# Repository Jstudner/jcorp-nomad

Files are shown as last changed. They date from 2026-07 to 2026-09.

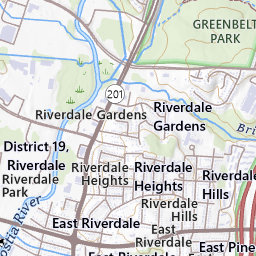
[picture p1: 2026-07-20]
SD_Card_Template/Maps/dc/tiles/14/4691/6263.jpg

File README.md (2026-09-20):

# <div align="center">Jcorp Nomad</div>

<div align="center">
  Jcorp Nomad Offline Media Server
</div>

<p align="center"><b>A portable, offline media server powered by the ESP32-S3 in a thumbdrive form factor.</b><br>
Stream movies, music, books, and shows anywhere - no internet required.</p>

<p align="center">
  
  
  
  
</p>

<p align="center">
  <a href="https://nomad.jcorptech.net"><b>Buy a Prebuilt Nomad</b></a> &nbsp;|&nbsp;
  <a href="https://ko-fi.com/jcorptech"><b>Support on Ko-fi</b></a>
</p>

---

> **Firmware 4.6** - The biggest update since Mk4, and everything in it has come over from the experimental branch. exFAT card support, offline maps with turn by turn directions, game ROMs and a shelf of built-in games, local multiplayer, TV support over DLNA, a WiFi Mode that joins your home network, offline translation, and recipe + 3D model libraries. Everything from Mk4 is still here and still works, this adds on top of it.
>
> Some of this is newer than the rest. The parts I'd call settled are exFAT, the reader and the media pages. Maps, WiFi Mode, DLNA and Translate work are all tested in full, but they have had less time in front of other people's hardware than the rest of the project. Known rough edges are listed near the bottom, everything works but some is getting more improvments so its user friendly. Maps in particular is tricky right now. 
>
> Firmware and the SD card template both change here, so you'll need to reflash and refresh your card files.
>
> Also making a push to migrate fully to exfat, will be keeping fat32 legacy support so yall dont have to reformat your cards, but some of the advanced features will only work on exfat.

---

## What is Nomad

Jcorp Nomad is an open-source offline media server designed for travel, remote work, classrooms, camping, and more. It runs entirely on an ESP32-S3, creates a local Wi-Fi hotspot, and serves media through a browser interface. Multiple users can access separate media streams simultaneously, all without internet access.

This project is compact, easy to modify, and includes optional 3D-printable hardware. Both firmware and web interface are fully open-source.

---

## Get a Nomad

### Build It Yourself (Recommended)

I strongly recommend building your own Nomad. It's not a very difficult project, if you can follow instructions and plug in a USB cable, you can do it. The parts are cheap, widely available, and the whole build takes under an hour. See Hardware Requirements and Quick Start below. If nothing else please check out the DIY option before purchasing. 

### Buy a Prebuilt

That said, I also won't say no to money. If you'd rather skip the DIY and get a ready-to-go unit, prebuilt Nomads are available at **[nomad.jcorptech.net](https://nomad.jcorptech.net)**.

Every Nomad, whether you build it or buy it, runs the same open-source firmware and web interface. When new features and updates are released, you can always flash the latest code yourself to stay up to date. 

### Support Development

If you just want to support the project, donations are always appreciated:  
**[ko-fi.com/jcorptech](https://ko-fi.com/jcorptech)**

---

## What's New in 4.6

### exFAT Support

This is the big one, and it's the thing people have been asking for the longest. FAT32 has been Nomad's biggest limitation since day one, cards over 32GB needed a reformat first, and no single file could go over 4GB, which is why large ZIMs had to be split into parts. exFAT fixes both of those.

- Cards mount as **exFAT, FAT32 or FAT16**, auto detected at boot, nothing for you to configure
- SDXC cards (anything over 32GB) work exactly as they come out of the package, no reformat step at all
- Single files can go over 4GB now, so a full size Wikipedia can sit on the card as one file instead of split parts
- Old FAT32 cards keep working exactly like they always did, this is additive, not a migration
- Writing to a nearly full card is a lot less likely to stall out, that was behind a lot of the upload and save timeouts

The reason this took so long, the Arduino ESP32 core ships a prebuilt filesystem library with exFAT compiled out of it, and there is no way to turn it back on from a sketch. The fix was to stop using it entirely and swap in SdFat, which brings its own filesystem code. Everything else in the firmware talks to it the same way it always did.

**You'll need the SdFat library installed** from the Arduino Library Manager before this will compile.

### Offline Maps

- Map regions live in `/Maps` and get browsed offline, with place search and real turn by turn directions (Drive and Walk)
- Regions are prepped on your PC with Nomad Tools, which downloads the map picture and the road network for the areas you pick
- Reads map data straight out of a packed archive instead of unpacking it onto the card, which keeps a region at roughly its download size instead of several times bigger

This one is the roughest of the bunch. It works, but it's slow, big regions take a while to draw. I'm still working on that, have a few ideas to improve the speed.

### WiFi Mode (join your home network)

Instead of running its own hotspot, Nomad can now join a WiFi network you already have and serve everything to that network, the browser interface, DLNA, all of it. Your phone stays on your normal internet-connected WiFi and Nomad is just another device on it. This is also the fix for TV devices like Fire Sticks that refuse to do anything on a network with no internet.

- Set it up from the admin panel: **WiFi Mode** button in the top bar opens a popup with a network scanner, password field, and an auto-reconnect option
- The captive portal turns itself off in this mode (hijacking DNS on someone's home network is uhh.. lets say frowned upon), and the screen shows the IP address the router assigned instead of a hotspot name

### TV Support (DLNA)

Nomad now shows up as a media server on anything that speaks DLNA - smart TVs, VLC, Kodi, Roku Media Player.

- Browse Movies, Shows, Music and Gallery straight from the TV, with cover art, and seeking works
- On the TV side there's nothing to set up, it just appears in the device list
- Works on the hotspot or in WiFi Mode; for Fire Sticks use WiFi Mode and the VLC app, since Fire OS breaks without internet now (so lame)
- Toggle it off in the admin panel if you don't want Nomad announcing itself / makes everything else a bit faster

### Offline Translation

A Translate page that works with zero internet. Two people can pass a phone back and forth and each type in their own language.

- Language packs live in `/Translate` on the card and are installed with Nomad Tools, which always grabs both directions of a pair
- Translation runs in the browser of whoever connected, nothing heavy runs on the Nomad itself
- will be very slow to load the first time, but after that back and forth is fairly quick, and the info is cached so its quick if you load it again.  
- I will be working on a voice integration on device for this aswell, but most keyboards include it already so voice to voice should be possible too. 

### Cookbook & Workshop

Two new library pages, both optional, both disabled by default.

- **Cookbook:** drop `.md`, `.cook` or `.json` recipe files into `/Cookbook` (photos work, same-name image convention). Recipes render with ingredient and step checklists you can tick off while cooking.
- **Workshop:** drop `.stl`, `.3mf` or `.obj` files into `/Workshop` and preview them in 3D right in the browser. A README or notes file in a folder describes every model in it. The viewer is a few hundred lines of raw WebGL, not a bundled 3D engine, so it stays fast off the card.

- I think these are kinda dumb... but I needed a clean number of pages so this is what we get..
### Game ROMs & Built-in Games

- Drop ROMs into `/Games` and play them in the browser through EmulatorJS
- Ships with Go, Chess, Connect Four, Tic-Tac-Toe, 2048, Minesweeper, Snake, Crazy Eights, Dots and Boxes, and a shared Whiteboard, all just plain HTML files
- Also ships with **DOOM** - the shareware WAD is included, and any `.wad` you drop in `/Games` runs through the same engine (this is here so I can say it runs doom, you must keep this on the card it is load bearing.. I swear lol)
- Cover art works the same as everywhere else, drop an image with the same name next to the file
- Add or remove games by adding or deleting files, there's nothing to configure, this works for the inbuilt games aswell. 

### Local Multiplayer

- Two player game rooms for multidevice use. 
- One person makes a room, shares the 4 character code, the other joins from their own phone
- Chess, Go, Connect Four and Tic-Tac-Toe all support it, the Whiteboard is just a shared freeform board
- There are also "pass and play games" that only need one device, I will eventualy make this an option for all of the defaults. 
- I plan to expand this so most games can run in pass and play or proper multi device mode. 

---

## Mk4 Highlights

### Offline Wikipedia & Archive Support (ZIM)
- Browse and search full offline Wikipedia (and other ZIM archives like Gutenberg and TED) directly from the SD card
- Search is fast even on massive archives, the companion [Nomad Tools](https://github.com/Jstudner/Nomad-Tools) app prebuilds a compact index on your PC, so the device never has to search the raw multi-gigabyte file itself
- Embedded videos and epub books inside archives play/read right in the browser
- Currently tested with Gutenburg epubs, TedX Videos, and wikipedia from the tiny 0.8 file all the way to the 140gb maxi with images. 

### Redesigned Case
<p align="center">
  Nomad Mk4 exploded case view
</p>

- New case slides together **front-to-back** instead of the old top-to-bottom design
- No more direct pressure on the screen, which was a common cause of cracked/broken screens on the old case
- Buttons stay exposed on the outside, so you can still flash firmware or hit the boot button without disassembling anything

### Indexing & Stability
- Root-caused and fixed a long-standing random reboot bug tied to files over 2GB, this was the actual cause of crashes on image-heavy Wikipedia pages and big movie scrubbing
- Fixed a heap-corruption crash that could hit when indexing and refreshing SD totals at the same time
- Boot-time indexing now only re-scans when files have actually changed, instead of a full scan on every boot
- Removed the screens loading spinner that was silently forcing a full-screen redraw every loop, pulling it out made the whole device noticeably more stable

### Reader & Memory Improvements
- Comic and PDF readers now free old pages from memory as you scroll, fixing crashes on long comics and scanned PDFs
- PDF viewer shows a real loading percentage instead of a blank screen
- Cleaned out a bunch of dead code and unused libraries that were loading on every Books page

### UI & Admin Updates
- Unified header and button styling across pages so themes apply consistently everywhere
- Fixed several dark mode readability bugs (unreadable resume text, buttons that ignored custom themes, etc.)
- Admin panel settings are now gated behind a login
- Fixed a stuck brightness slider caused by an out-of-range default value

### Default Themes (28)

Default Blue, Forest Night, Cherry Blossom, Mocha Latte, Ocean Depths,
Autumn Leaves, Lavender Fields, Sunset Horizon, Coral Reef, Mountain Mist,
Jade Garden, Desert Sand, Arctic Aurora, DeLorean, Midnight Code, 90s Retro,
Mint Breeze, Rose Gold, Crimson Night, Emerald Dream, Royal Purple,
Copper Sunset, Sapphire Sea, Peach Cream, Slate Storm, Lime Zest,
Burgundy Wine, Teal Oasis

---

## Features

- **exFAT & FAT32:** Any card format, auto detected at boot. Cards over 32GB and files over 4GB both work.
- **WiFi Mode:** Join an existing WiFi network instead of running the hotspot, with automatic fallback so you can't lock yourself out.
- **TV Support (DLNA):** Shows up as a media server for smart TVs, VLC, Kodi and friends, with cover art and seeking.
- **Offline Encyclopedia:** ZIM archive support for offline Wikipedia and other offline wikis, with fast on-device search.
- **Offline Maps:** Browsable map regions with place search and turn by turn directions, served straight off the card.
- **Offline Translation:** In-browser translation between installed language pairs, no internet ever.
- **Games:** Browser-based ROM playback through EmulatorJS, DOOM, plus ten built-in games.
- **Local Multiplayer:** Two player game rooms over the Nomad's own Wi-Fi, no internet needed.
- **Cookbook:** Recipe library with tick-off ingredient and step checklists.
- **Workshop:** 3D-print model library with an in-browser STL/3MF/OBJ preview.
- **Subtitles:** Sidecar subtitle files attach themselves to a video by filename, with selectable language tracks.
- **Chat:** A simple local chat room for everyone connected to the Nomad.
- **Admin Panel:** Full device controls, library indexing, Theme Customizer, menu page toggles, login-gated settings.
- **File Browser:** Upload, rename, delete, download, and inline file editing. (Recommended to use a PC)
- **Global Search:** Quickly find media across all categories from the Menu page.
- **Music Player:** Seamless background playback with subdirectory playlists and a dynamic Queue.
- **Movies & Shows:** Plyr-integrated playback with season/special folder support.
- **Digital Library:** EPUB support, PDF handling, and a dedicated Comic/Webtoon reader.
- **Resume Tracking:** Saves playback progress for Movies, Shows, and certain Books.
- **Gallery & Files:** Dedicated pages for image viewing, video clips, and general file sharing.
- **Captive Portal:** Automatic login/redirection for easy access.
- **Persistent Settings:** Themes and system configurations saved across reboots.
- **Mobile-Friendly UI:** Fully responsive design optimized for handheld offline streaming.

---

## Hardware Compatibility

Nomad is built specifically for the **Waveshare ESP32-S3 Dev Board (1.47" LCD version)**. Due to the number of low-level tricks used to squeeze this much functionality out of the hardware, it is difficult to get Nomad running on other boards.

There are a few community forks that target other ESP32 boards, but your mileage will vary. I'm also actively working on a **Nomad Lite** version with wider board compatibility, focused on basic streaming without all the advanced features.

---

## Hardware Requirements

- **Waveshare ESP32-S3 Dev Board (1.47" LCD version)** - [Amazon Link](https://amzn.to/4ktB6oT)

- **or the ESP32-S3-LCD-1.47B** - the USB-C board. Same chip, same everything, the LCD backlight just moves from GPIO 48 to GPIO 46. Building it yourself, set `BOARD_USB_C` to 1 in `Display_ST7789.h`; flashing from the browser, pick the USB-C build. Get it wrong and it boots functional, just no screen output. - [Amazon Link](https://link.amazon/B03vYZlXB)

- **microSD card, exFAT or FAT32 (16-128GB recommended, up to 2TB)**
  [Amazon Link](https://amzn.to/44tM1c4)

- **SD-Card Extender (optional, 3DP case compatible)**
  [Amazon Link](https://amzn.to/45IWIJz)

- **USB power source**
- **Optional:** 3D-printed enclosure (STL files included)

---

## Flash It From Your Browser

If you would rather skip Arduino IDE entirely, **[nomadflash.jcorptech.net](https://nomadflash.jcorptech.net)** does the setup from a browser tab. The firmware is already compiled, so there is nothing to install and no SdFat version to line up. This system will lag a bit behind on the latest version, but makes setup much easier for most casual users. 

It covers three things:

- **Flash the firmware.** Plug Nomad into a USB port, pick a build, and it writes the bootloader, partition table and app in one image. Takes less than a minute.
- **Set up the SD card.** Copies the web interface onto the card and creates every media folder Nomad uses, including Games, Maps, Cookbook and Workshop. There is an optional test set of placeholder content if you want to see every page working before you load your own media.
- **Update an existing card.** Replaces only the interface files and leaves your media alone. (still WIP)

Both the main and experimental builds are there, and each is offered for both boards:

- **USB-A** for the ESP32-S3-LCD-1.47
- **USB-C** for the ESP32-S3-LCD-1.47B

Pick the one matching the connector on your board. The two differ only in which pin drives the LCD backlight, so flashing the wrong one boots fine but leaves the screen dark.

Formatting is the one step it cannot do, because a web page has no access to drives or partitions. You usually do not need it, since exFAT, FAT32 and FAT16 cards all mount as they come. If a card does need formatting, the site prints the exact command for Windows, macOS or Linux.

**Requires Chrome, Edge or Opera on a desktop.** It uses Web Serial and the File System Access API, which Firefox and Safari do not implement, and neither one works on iOS or Android.

---

## Software Requirements

- Arduino IDE, with the **esp32 board package 3.3.3**
- Arduino libraries, exact versions. These are what the shipped build compiles against, and mismatches here are the single most common build failure:
  - `ArduinoJson` by Benoit Blanchon **7.3.0**
  - `Async TCP` by ESP32Async **3.4.7**
  - `ESP Async WebServer` by ESP32Async **3.7.1**
  - `LVGL` by kisvegabor **8.4.0**
  - `SdFat` by Bill Greiman **2.3.0** - this one is required for exFAT, it is not optional
- SquareLine Studio (optional, for UI editing)

If you would rather not line any of that up, use the browser flasher above.

---

## Quick Start

1. Flash ESP32-S3 firmware from `/firmware/`.
2. Copy `/SD_Card_Template/` files onto the card. Any exFAT or FAT32 card works as-is, you only need to format if the card is brand new or broken.
3. Place media in `/Movies`, `/Shows`, `/Books`, `/Music`, `/Gallery`, `/Files`, `/Games`, `/Cookbook`, `/Workshop`. (ZIMs, Maps and Translate packs get prepped with Nomad Tools, see below.)
4. Insert SD card and power device via USB.
5. Connect to Wi-Fi `Jcorp_Nomad` with password: `password`.
6. Open the browser interface.
7. Click the gear icon → Library Index → **Full Scan Now**.
8. Monitor Admin Console for progress; scan may take minutes.
9. Return to Menu page and enjoy your media!
10. Optional: to serve your home network (and TVs) instead of running a hotspot, open Admin → **WiFi Mode** and join your network from there.

---

## Key Improvements

1. **Faster & More Reliable Indexing**
   - Non-blocking, background indexing for large libraries.
   - Safe on power loss; partial indexes remain intact.
   - Auto-updates changes; frontend detects updates automatically.
   - Boot-time indexing now only triggers on an actual file change, not every boot.

2. **Resume Functionality**
   - Movies and Shows track playback progress.
   - Options for **Play from Start** or **Resume**.
   - Menu displays last three movies/shows; mobile shows most recent.

3. **Dark Mode**
   - Toggleable across all pages from the menu.
   - Consistent theme tokens across pages, no more mismatched dark colors.

4. **Admin Page**
   - Full device control: shutdown, restart, flash mode, Wi-Fi, RGB LEDs, brightness, credentials, indexing, and file management.
   - Login-gated settings so changes require the admin password.
   - Safe shutdown option for SD card health.
   - Real-time system console feedback.

5. **Stability Improvements**
   - Fixed frontend NDJSON sync issues.
   - Crash recovery on large indexes.
   - Fixed a random-reboot bug tied to files over 2GB.
   - Dynamic LCD brightness adjustment.
   - Streaming stability enhancements.

6. **Improved Library Support**
   - Supports deeper folder structures for Shows and Music.
   - Flexible organization; media files can be nested at any level.

---

```
Folder Structure

/Movies
    Interstellar.mp4
    Interstellar.jpg

/Shows
    /The Office
        S01E01 - Pilot.mp4
        S01E02 - Diversity Day.mp4
    The Office.jpg

    /Gravity Falls
        /Season 1
            S1E1 - Tourist Trapped.mp4
            S1E2 - The Legend of the Gobblewonker.mp4
        /Season 2
            S2E1 - Scary-oke.mp4
            S2E2 - Into the Bunker.mp4
        Alex Hirsch Interview.mp4
    Gravity Falls.jpg

/Books
    The Martian.pdf
    The Martian.jpg
    /How to Train Your Dragon
        book1.pdf
        book2.mp3
        book1.jpg
        book2.jpg
    How to Train Your Dragon.jpg

/Music
    track01.mp3
    /Artist1
        track01.mp3
        /Album1
            track02.mp3
    /PersonName
        /Playlist1
            track01.mp3
        /Playlist2
            track02.mp3

/Gallery
    image01.jpg
    video01.mp4

/Files
    document.pdf
    example.txt

/Games
    Pokemon Red.gb
    Pokemon Red.png
    Doom.wad
    Chess.html
    Go.html

/Cookbook
    Grandma's Chili.md
    Grandma's Chili.jpg
    /Desserts
        Brownies.md

/Workshop
    /Brackets
        shelf bracket.stl
        README.txt

/Maps
    /pennsylvania
        manifest.json
        (map data, prepped with Nomad Tools)

/Translate
    manifest.json
    (language packs, installed with Nomad Tools)

/Archive
    wikipedia_en_all_maxi.zim
    /.nomad-zim
        (search index, built by Nomad Tools)

index.html
appleindex.html
menu.html
movies.html
shows.html
books.html
music.html
gallery.html
files.html
archive.html
games.html
maps.html
translate.html
cookbook.html
workshop.html
Logo.png
favicon.ico
```

---

## Supported Formats

- **Video:** `.mp4, .webm, .m4v` play everywhere. `.mkv, .avi, .mov` are listed and handed to the player too, but Nomad has no content type for them, so whether they play is down to your browser (Safari is usually fine with `.mov`, Chrome usually is not with `.mkv`). If a video lists but will not play, that is almost always this. Remux to `.mp4` and it will.
- **Audio:** `.mp3, .flac, .wav, .ogg, .aac, .m4a`, plus `.opus` with the same browser caveat as above.
- **Subtitles:** `.srt, .vtt, .ass, .ssa, .sub` - drop them next to the video with the same name. `Movie.srt` or `Movie.en.srt` both attach, language suffixes become selectable tracks, and `.srt` is converted to WebVTT on the fly because browsers render nothing for raw SRT.
- **Books:** `.pdf, .epub, .cbz, .cbr` 
- **Images:** `.jpg, .jpeg, .png, .webp, .gif, .bmp, .avif` 
- **Archives:** `.zim` (offline Wikipedia and other ZIM-format wikis), needs special processing, you cant just drop a .zim in sadly. Prep them with [Nomad Tools](https://github.com/Jstudner/Nomad-Tools) first (still rough, but handles most common ZIMs)
- **Games:** ROMs for the systems EmulatorJS supports (GB, GBC, GBA, NES, SNES, Genesis, and others), `.wad` files for DOOM, plus `.html` files for built-in games
- **Maps:** map regions prepped with Nomad Tools, dropped into `/Maps`
- **Recipes:** `.md`, `.cook`, or `.json` files in `/Cookbook`
- **3D Models:** `.stl`, `.3mf`, `.obj` in `/Workshop`
- **Translation:** language packs installed into `/Translate` with Nomad Tools

---

## Nomad Tools

Some content needs a one-time prep step on your computer before Nomad can use it, ZIM archives need a search index built, maps need downloading, translation packs need fetching. [Nomad Tools](https://github.com/Jstudner/Nomad-Tools) is a simple menu that does all of it. Windows and Linux (macOS untested).

Basic usage:

1. Download Nomad Tools and put your Nomad card in the computer.
2. **Windows:** double-click `START-Windows.bat`. **Linux:** run `./start-linux.sh`.
3. Pick your card from the list (or type its path), then pick a job from the menu.

What the menu covers:

- **Add ZIM archives** - copies Wikipedia/Gutenberg/etc. onto the card and builds the search index. Adds to what's there, never wipes your existing archives, and splits oversized files automatically.
- **Optimize cover images** - shrinks Movie/Show/Book covers so pages load fast on the device.
- **Rebuild media index** - refreshes the library listing after you've added or removed files from the PC.
- **Download offline maps** - grabs map tiles for an area you pick, with a size estimate and free-space check before anything downloads.
- **Build a routing map** - maps plus the road network and place search, for turn by turn directions. Pick from ready-made areas (any US state, big regions, or the whole country) and they join into one seamless map. US only for now
- **Add translation languages** - installs offline translation packs, always both directions of a pair. Comes in collections (`starter`, `traveler`, `europe`, `asia`, `world`) or single languages. (I recomend just grabbing all as its less than 4GB)

A good order for a fresh card: media and ZIMs first, optimize images, rebuild the index last. Maps and languages can be added any time.

---

## Known Rough Edges

Everything here works, but these are the parts I already know aren't great:

- **Maps are slow.** Big regions take a while to load and pan. It works, it's just not snappy yet, and that's the main thing I'm working on.
- **WiFi Mode and DLNA have seen few routers and few TVs.** They work (tested with VLC on a Fire Stick, desktop VLC, and phones), but there are a lot of both out there and I have tried a handful. If your TV can't find Nomad, tell me what TV it is and I will see what I can do.
- **Some video containers list but won't play.** `.mkv`, `.avi` and `.mov` get served without a content type, so it comes down to what your browser will sniff and decode. Nothing is broken on the Nomad side.
- **Set an admin password before using WiFi Mode.** On the hotspot only people you gave the password to can reach the admin panel. On your home network, everything on that network can. I dont hard gate this, but worth noting. 
- **Free space on FAT32 cards can read slightly wrong.** SdFat doesn't update the counter FAT32 keeps for it, so the number drifts by however much Nomad itself writes. It fixes itself the next time you plug the card into a PC, and it doesn't affect your files at all. exFAT cards aren't affected.
- **EmulatorJS cores download on first play.** Once cached they're fine, but the first launch of a system pulls the core off the card and takes a moment.
- The newer features have had a fraction of the testing the core has. If something breaks, tell me. Issues and PRs are both welcome.

---

## What's Next

**Nomad Lite** - A stripped-down version of Nomad with wider board compatibility, focused on core streaming features. In active development now that Mk4 is out.

**Gallion** - A larger-scale sibling to Nomad, built on more capable hardware. Gallion is designed to handle everything that couldn't fit on Nomad's current platform > ROM emulation, 4k video, and expanded media compatibility across the board. The current version is [here](https://github.com/Jstudner/Gallion).

**ESP32-P4** - I have said for a long time that I don't want to switch hardware, as doing so would leave yall with a useless board. The S3 is the Nomad and it stays supported. That said, I have started slowly co-developing a P4 version alongside it, because the P4 brings two things the S3 can't: a radio module that is already FCC certified, which matters a lot for anything I sell, and considerably faster WiFi. 

Two boards, if it works out. The **WIFI6** board is a stick, only a bit larger than the Nomad you have now. The **NANO** is noticeably bigger than either, but it adds an ethernet port with POE module support, and a USB port so storage can be expanded or replaced rather than living entirely on the SD card.

None of this is a replacement announcement. It will be its own branch, the S3 keeps getting the same updates, just better speed and a few more features on the p4 branch. 

---

## Project Inspiration

Inspired by my experience running a Jellyfin server, I wanted a portable, low-cost solution for offline media streaming. Challenges with SBCs (Raspberry Pi, etc.) included high power usage, heat, and instability.

Nomad focuses on delivering:

- Offline access
- Wide device compatibility
- Simple frontend for media browsing and playback
- Multiple user support
- High customization potential

The ESP32-S3 provides enough performance to handle these requirements efficiently, in a pocket-sized form factor.

---

## License

[CC BY-NC-SA 4.0](https://creativecommons.org/licenses/by-nc-sa/4.0/) - free to remix and share for non-commercial use with attribution.

---

## Credits

Developed by **Jackson Studner (Jcorp Tech)**.
Inspired by open-source offline media projects. Contributions via PRs welcome.

<p align="center">
  
</p>

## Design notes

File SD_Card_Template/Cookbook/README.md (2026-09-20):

# Cookbook

Recipes for the Nomad's Cookbook page. Drop files in here, then turn the page on
in **Admin → Menu Pages → Cookbook** (it ships off).

Subfolders become categories — `Cookbook/Bread/Cornbread.md` shows up under
"Bread". One level deep; anything deeper isn't scanned.

## Writing recipes on the Nomad itself

You don't have to prepare files on a computer. The Cookbook page has a
**＋ New recipe** button that writes straight to this folder, and an **Edit**
button on every recipe. What it saves is ordinary Markdown in the format below,
so a recipe typed on a phone is still a plain file you can open on a PC later.

Editing and deleting follow the admin's **Allow uploads** switch — turn that off
and the Cookbook becomes read-only, without hiding the recipes.

## Timers

Any time written into a step becomes a tappable timer: "bake 20-25 minutes"
gets a **⏲ 20 min** button beside it (ranges start at the low end, so you come
back and check). There's also a manual timer at the bottom of the dock.

Timers keep running while you move around the page, survive a reload, hold the
screen awake, and beep when they finish. They're per-browser, not stored on the
card, so two people cooking from the same Nomad don't fight over them.

## Three formats

Any of them works, and they can be mixed in the same folder.

### Markdown (`.md`) — easiest to type by hand

```markdown
---
title: Skillet Cornbread
servings: 8
time: 35 min
category: Bread
tags: cast iron, quick
source: Grandma
---

A crisp-edged cornbread that comes out of a hot skillet.

## Ingredients
- 1 cup cornmeal
- 1 cup flour
- 1 1/2 tsp salt
- 2 eggs

## Steps
1. Heat the oven to 425°F with the skillet inside.
2. Whisk the dry ingredients together.
3. Bake 20-25 minutes until the top springs back.

## Notes
Buttermilk instead of milk makes it tangier.
```

The `---` block at the top is optional; so is every field in it. A `# Heading`
before the first section works as the title if there's no front matter.

### JSON (`.json`) — easiest to generate

```json
{
  "title": "Skillet Cornbread",
  "servings": 8,
  "time": "35 min",
  "category": "Bread",
  "tags": ["cast iron", "quick"],
  "ingredients": ["1 cup cornmeal", "1 1/2 tsp salt", "2 eggs"],
  "steps": ["Heat the oven to 425°F.", "Bake 20-25 minutes."],
  "notes": "Buttermilk instead of milk makes it tangier."
}
```

Ingredients may also be objects — `{"qty": 1, "unit": "cup", "item": "cornmeal"}` —
which come out as the same scalable line.

### Cooklang (`.cook`) — recipe-as-a-sentence

[Cooklang](https://cooklang.org) tags ingredients, cookware and timers inline in
the method, and the ingredients list builds itself:

```cooklang
>> title: Cooklang Pancakes
>> servings: 4
>> time: 20 minutes
>> course: Breakfast

Whisk the @flour{200%g}, @milk{300%ml} and @eggs{2} in a #mixing bowl{}.

Cook a ladle of batter in a #frying pan{} for ~{2%minutes} until it bubbles,
then flip. Serve with @maple syrup{}.
```

`@ingredient{qty%unit}` (use `{}` when the name is more than one word),
`#cookware{}` and `~timer{5%min}` are lifted out automatically; `>> key: value`
lines are metadata (`servings` still drives scaling). See
`Example - Cooklang Pancakes.cook`.

## Photos

An image with the same name as the recipe becomes its photo:
`Skillet Cornbread.md` + `Skillet Cornbread.jpg`. Or set `image:` in the recipe
to any path on the card.

## Serving scaling

The page reads the leading amount off each ingredient line and multiplies it
when you change the serving count. It understands `2`, `1.5`, `1/2`, `1 1/2`,
`½`, `1½`, and ranges like `2-3` or `2 to 3`.

Lines that don't start with a number — "salt to taste", "a handful of parsley" —
are left exactly as written, because they don't scale. Unit names aren't
converted either: 8 tsp stays 8 tsp rather than becoming 2 tbsp 2 tsp.

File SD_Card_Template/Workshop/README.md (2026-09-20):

# Workshop

3D models for the Nomad's Workshop page. Drop files in here; the Workshop tile
appears on the menu as soon as this folder has anything in it.

Subfolders become collections — `Workshop/Repairs/Hose Clip.stl` shows up under
"Repairs". One level deep; anything deeper isn't scanned.

## What can be previewed

| Format | On the page |
|---|---|
| `.stl` (binary or ASCII) | Full 3D preview, dimensions, triangle count |
| `.obj` | Full 3D preview |
| `.3mf` | Full 3D preview, including multi-part plates |
| `.gcode`, `.step`, `.f3d`, `.scad`, `.zip`, and friends | Listed and downloadable, no preview |

The preview is drawn with plain WebGL off the card — nothing is fetched from the
internet, and no slicer is involved.

## Thumbnails and descriptions

Files that sit next to a model and share its name are picked up automatically:

```
Hose Clip.stl          the model
Hose Clip.jpg          its photo
Hose Clip.md           its description / print notes
README.md              a description shared by everything in this folder
```

A few common suffixes are understood too, so all of these attach to
`Hose Clip.stl` rather than being ignored:

```
Hose Clip-notes.md
Hose Clip.description.txt
Hose Clip print settings.txt
```

An exact name match always wins over a suffixed one. Images may be `.jpg`,
`.png`, `.webp`, `.gif` or `.bmp`; descriptions may be `.md`, `.txt` or `.nfo`,
and are shown as plain text, so write them however you like. A folder-wide
description can be called `README`, `notes` or `description`.

Where the photo shows up:

- in the grid, as the model's thumbnail
- for `.stl` / `.obj` / `.3mf`, behind a **Photo** button next to the 3D view,
  so you can compare the model with how it actually printed
- for everything else — `.gcode`, `.step` and friends — the photo *is* the
  preview, filling the space where the 3D view would be

## Print check

The model view compares the model's real bounding box against a build volume you
set once (stored in your browser, not on the card). It counts a part as fitting
if it fits either way round on the plate, since rotating 90° costs nothing.

Dimensions come from the model's own geometry, so this only applies to the
formats that get parsed — a `.gcode` or `.step` is reported as unknown rather
than guessed at.

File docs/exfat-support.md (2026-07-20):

# exFAT + FAT32 SD card support

Nomad firmware 4.6 replaces the Arduino `SD_MMC` filesystem stack with
**NomadSD** (`firmware/JcorpNomadProject/NomadSD.h/.cpp`), which mounts
**exFAT, FAT32 and FAT16** cards interchangeably, auto-detected at boot.

Cards larger than 32 GB work exactly as they come out of the box, since SDXC
cards ship exFAT. Existing FAT32 cards keep working unchanged: format support
is additive, not a migration.

## Why SD_MMC could never do exFAT

The Arduino-ESP32 core links a **precompiled** ESP-IDF FATFS library built with
`FF_FS_EXFAT = 0`. No sketch-level setting can re-enable it, so `SD_MMC`,
`FFat` and anything else on `esp_vfs_fat` is FAT32-only, permanently. Years of
attempts through that stack went nowhere because the limit lives in a `.a` file.

## How NomadSD works

```
sdmmc_host driver (same SDMMC peripheral + pins as before)
  -> SdMmcBlockDev        raw-sector block device (FsBlockDeviceInterface)
    -> SdFat FsVolume     auto-detects exFAT / FAT32 / FAT16 at mount
      -> fs::FSImpl wrap  standard Arduino fs::FS + fs::File
        -> NomadSD        drop-in for SD_MMC (`#define SD_MMC NomadSD`)
```

SdFat carries its own MIT-licensed FAT/exFAT implementation, so the locked IDF
FATFS is no longer used. The web server, indexer and every existing `SD_MMC.*`
call site work unchanged through `fs::FS`.

## Build requirements

- **SdFat library** >= 2.3.0 (Library Manager: "SdFat" by Bill Greiman).
- `build_opt.h` in the sketch folder, already in the repo. The ESP32 core picks
  it up automatically in both the IDE and arduino-cli. It sets
  `USE_BLOCK_DEVICE_INTERFACE=1`, UTF-8 long filenames, and incremental
  free-space accounting.
- Board settings and partition scheme are unchanged.

## What this buys

### Files larger than 4 GB stream

`fs::File` is 32-bit end to end: `size()`, `position()` and `seek()` all use
`size_t`, so a 5 GB file reported 0.88 GB and could not be seeked past 4 GB.
That API is fixed by the core.

`NomadFile64` (in `NomadSD.h`) is a 64-bit read handle used by the HTTP range
handler instead. Sizes come from `NomadSD.fileSize64()`, offsets parse with
`strtoull`, and the stream table stores `uint64_t`. Two related fixes:

- A range starting beyond EOF returns **416** with a `Content-Range`, per
  RFC 9110, instead of being silently clamped.
- Any single response body is capped at 256 MB so it fits `size_t`. A plain GET
  of a larger file degrades to **206** with an honest `Content-Range` rather
  than a truncated 200; clients fetch the next slice, which media players and
  the ZIM reader already do.

### `size()` saturates instead of wrapping

`NomadFileImpl::size()` returns `SIZE_MAX` past 4 GB rather than wrapping to a
small number. `SIZE_MAX` doubles as a sentinel: the indexer, file browser and
usage scanner check for it and only then pay for a `fileSize64()` lookup.
Normal files, and every file on a FAT32 card, cost nothing extra.

### The 2 GB stdio guard is gone

Mainline had to close and reopen a streaming handle crossing 2 GB, because
`fs::File` sat on newlib stdio whose signed 32-bit offset corrupted the FILE
buffer on a reused handle. SdFat does not use stdio and seeks 64-bit natively,
so deep seeks no longer pay a close/reopen, on exFAT and FAT32 alike.

### Fewer stalls on full cards

Creating a file no longer scans a huge FAT for free clusters, which was the
main aggravator behind `/save` and `/upload` watchdog resets on nearly-full
cards. Contiguous-file seeks are O(1) instead of a cluster-chain walk.

### File timestamps

An `FsDateTime` callback is installed at mount. Without one every file the
device writes gets an identical constant date. The device is offline with no
RTC, so this uses the fixed-epoch-plus-uptime approach already used for OPDS
timestamps: not wall time, but files written later in a session sort after
earlier ones.

## Behaviour notes

- The boot log and admin console report the detected filesystem and bus mode,
  e.g. `Mounted 4-bit @ 40MHz (exFAT)`.
- Mount tries 4-bit/40 MHz, then 4-bit/20 MHz, then 1-bit/20 MHz. The last rung
  matches the old behaviour, so any board or card that cannot do 4-bit still
  comes up.
- **USB mode no longer mounts a filesystem.** MSC passes raw sectors and the
  host PC handles the format. The old `format_if_mount_failed=true` in USB mode,
  which could silently reformat an exFAT card as FAT32, is gone.
- FAT32 free space is read from the FSInfo sector; exFAT uses the allocation
  bitmap. A card with broken FSInfo falls back to a one-time full FAT walk.
- All SD I/O is serialized by one recursive mutex inside NomadSD, replacing the
  FATFS `FF_FS_REENTRANT` volume lock.

## Verification

`arduino-cli` build: 50% flash, 42% RAM, 720 bytes below mainline.

Filesystem behaviour is covered by a host harness linking the same SdFat version
the firmware uses, through the same block-device interface, against real disk
images. All 30 checks pass:

- **FAT32**: mounts through the same part1-then-superfloppy order, finds root
  and nested files written by an external tool, reads correct content, reports
  exact sizes, seeks, iterates directories, and round-trips a new file.
- **exFAT**: mounts, reports correct volume geometry, creates a 5 GiB file,
  reports the full 64-bit size, seeks past 4 GiB, writes and reads back a marker
  there, and survives a reused handle crossing the 2 GiB and 4 GiB lines, the
  exact pattern that used to corrupt newlib stdio.

`fsck.exfat` reports the SdFat-written volume clean.

## Known issue: FAT32 free-space counter drifts

`fsck.vfat` on a FAT32 image after SdFat wrote to it reports:

```
Free cluster summary wrong (129815 vs. really 129814)
```

SdFat does not update the FAT32 **FSInfo** sector when it allocates clusters.
The old FATFS did, so this is a small regression on FAT32 cards only.

- **Scope**: drifts by exactly the clusters the device itself writes (index
  files, config, uploads). File data is unaffected and nothing risks corruption.
- **Visibility**: FSInfo is advisory. Windows and Linux recompute free space
  rather than trusting it; only `chkdsk`/`fsck` remarks on it, and any PC write
  resets it. The dirty bit is not set, so there is no "repair this drive" prompt.
- **Effect on us**: `usedBytes()` seeds from FSInfo for a fast boot and inherits
  the drift. The firmware will not trust that fast path until
  `reconcileStatTrust()` agrees with a real walk to within 2%.
- **Not applicable to exFAT**, which has no FSInfo.

Fixes if it ever matters: write a corrected FSInfo at unmount, or mark FSInfo
unknown (`0xFFFFFFFF`, explicitly legal) on first write and accept one full FAT
walk on the next boot. Neither is implemented; the current behaviour is bounded
and self-correcting.

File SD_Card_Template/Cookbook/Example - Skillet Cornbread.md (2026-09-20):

---
title: Skillet Cornbread
servings: 8
time: 35 min
category: Bread
tags: cast iron, quick, side
---

Crisp-edged cornbread baked in a skillet that goes into the oven empty and hot.
Delete this file once you've added recipes of your own — it's here to show the
format.

## Ingredients
- 1 cup cornmeal
- 1 cup flour
- 2 tbsp sugar
- 1 1/2 tsp salt
- 2 tsp baking powder
- 1 1/4 cups buttermilk
- 2 eggs
- 6 tbsp butter
- salt to taste

## Steps
1. Put the skillet in the oven and heat both to 425°F.
2. Whisk the cornmeal, flour, sugar, salt and baking powder together.
3. Beat the buttermilk and eggs, then stir them into the dry mix until just combined — a few lumps are fine.
4. Melt the butter in the hot skillet, swirl to coat, and pour the rest into the batter.
5. Pour the batter into the skillet. It should hiss.
6. Bake 20-25 minutes, until the top springs back and the edges have pulled away.
7. Turn it out onto a board and cut it in the skillet's shape.

## Notes
Try the serving buttons above the ingredients — the amounts rescale as you go.
"salt to taste" stays put, because that one doesn't scale.

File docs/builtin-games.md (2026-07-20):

# Built-in games system (Games bucket)

## How it works

Any `.html` file inside `/Games` on the SD card is treated as a **built-in game**
and shows up on the Games page (`games.html`) as a card in the same grid as ROMs:

- Built-ins are **pinned above the ROM list** and are not re-ordered by the sort
  dropdown. Pin order is the `BUILTIN_ORDER` list in `games.html`
  (`go`, `connect four`, `chess`, `tic-tac-toe`, `whiteboard`); anything not in
  the list follows alphabetically.
- The card label is the filename without `.html` (`Connect Four.html` becomes "Connect Four").
- **Cover art** uses the same sidecar convention as ROMs: put an image with the
  same basename next to the file (`Go.png` beside `Go.html`) and it becomes the
  card cover. Until then the shared `placeholder.jpg` is used.
- **Add / remove**: drop an `.html` in `/Games` to add it; delete the file to
  remove it from the frontend. Nothing else to configure. (The Games index
  rebuilds on demand: after changing files via USB, the next visit may briefly
  show "Building game index".)
- The console filter dropdown hides built-ins (they have no console); the search
  box still matches their names.

Shipped built-ins live in `SD_Card_Template/Games/`:

| File | Needs | Notes |
|---|---|---|
| `Go.html` | `/assets/tenuki.min.js` (MIT, engine-only esbuild bundle of tenuki 0.3.1) | 9×9 / 13×13. 19x19 is not offered because the move list would outgrow the 512-byte MP state. |
| `Connect Four.html` | none | |
| `Chess.html` | `/assets/chess.min.js` (chess.js **0.12.1**, BSD-2) | 0.13+ is ESM-only and breaks as a classic `<script>`, so do not "upgrade" it. |
| `Tic-Tac-Toe.html` | none | |
| `Whiteboard.html` | none | Not a room game, see below. |

All two-player games share `/assets/mp-client.js` (HTTP short-polling against the
firmware's `/api/mp/*` room store: 4-char room codes, seat 0 = creator, turn =
`seq` parity, state = one opaque string ≤ ~500 bytes replaced on every move).

### Go state encoding

`{"s":13,"m":"ddqf..pp"}` where `m` is the move list, two chars per move
(`'a'+x`,`'a'+y`), `..` = pass. Every client rebuilds the position by replaying
the list into a fresh tenuki game, which also hands mid-game joiners the whole
board on their first poll. Scoring note: territory score is shown after two
passes **without dead-stone marking**, so casual-play accuracy only.

## Whiteboard

Same control set as the old Gallion whiteboard (Private/Live modes, undo/redo,
color, pen size, erase, clear, save, load) but the live board syncs through the
SD card instead of sockets (the firmware has none):

- Every participant writes **their own stroke layer** to
  `/.whiteboard/wb_<clientid>.json` via the open `POST /save` handler (atomic
  temp+rename on the firmware side), throttled to ≥0.9 s between writes and
  capped at 24 KB per layer.
- Everyone polls `GET /listfiles?dir=/.whiteboard` every 2.5 s and refetches only
  layers whose file size changed. Per-client layers mean no lost strokes from
  concurrent drawing.
- **Clear** on the live board `POST /delete`s every layer file. Other clients
  detect the wipe because their own file disappears from the listing, and reset.
- The private board autosaves strokes to `localStorage`; **Save** downloads a
  PNG, **Load** (private only) draws an image file onto the canvas.
- The `/.whiteboard` dotfolder is invisible to the media indexers (dot-prefixed)
  and is created on first save via `POST /mkdir`.

## EmulatorJS (ROM cards)

- Runtime lives at `/EmulatorJS/data/` (loader.js, emulator.min.js/.css,
  version.json, `compression/`, `localization/`, `cores/`).
- Cores staged on the card (4 build variants each): gambatte (GB/GBC),
  fceumm (NES), snes9x (SNES), genesis_plus_gx (Genesis/Master System),
  mgba (GBA) ≈ 24 MB. More cores: copy `<core>/*.data` from the EmulatorJS
  repo's per-core directories into `data/cores/`.
- `data/cores/reports/<core>.json` must exist per core or EmulatorJS disables
  **core caching** (the ~1 MB core re-downloads on every play, costly over the
  ESP32 link). The report content is trivial build metadata
  (`{"core":...,"buildStart":...,"buildEnd":...,"options":{}}`); synthesized
  ones are fine. The core itself downloads only after the user taps Start Game.
- `games.html` maps UI console ids to EmulatorJS system keys before launch
  (`gbc` to `gb`, `genesis` to `segaMD`, `sms` to `segaMS`), since EmulatorJS has **no** `gbc`
  system key; an unmapped id makes the loader fetch a nonexistent core and die.
- An "Exit Game" bar appears above the emulator; exiting reloads the page
  (EmulatorJS cannot be torn down and restarted in one page lifetime).
- Save states/saves persist in the browser (IndexedDB), keyed by ROM path
  (`EJS_gameID`).

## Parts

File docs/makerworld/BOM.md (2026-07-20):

# Jcorp Nomad Mk4 — Bill of Materials

Total cost: roughly **$20–30** depending on SD card size.

## Electronics

| # | Part | Qty | Notes | Link |
|---|---|---|---|---|
| 1 | Waveshare ESP32-S3 Dev Board, **1.47" LCD version** | 1 | The only supported board — Wi-Fi, display, SD slot, and USB-A plug all on one PCB. No substitutes without firmware work. | [Amazon](https://amzn.to/4ktB6oT) |
| 2 | microSD card, 16–128 GB (up to 2 TB supported) | 1 | **Class 10 / U1 or better** — Nomad is very read-heavy and a fast card noticeably improves performance. Must be formatted FAT32. | [Amazon](https://amzn.to/44tM1c4) |
| 3 | USB power source | 1 | Any USB-A port, charger, or power bank. | — |

## Optional

| # | Part | Qty | Notes | Link |
|---|---|---|---|---|
| 4 | microSD extender (case-compatible length) | 1 | Swap the card from the back of the case without disassembly; also moves the card away from board heat. | [Amazon](https://amzn.to/45IWIJz) |
| 5 | Small thermal pad or dab of thermal paste | 1 | Between the ESP32-S3 chip and case shell. Not required — air cooling works fine. | — |

## Printed parts

| # | Part | Qty | Material | Notes |
|---|---|---|---|---|
| 6 | Nomad Mk4 case body | 1 | **PETG** (recommended) or quality PLA | ~10–15 g total. No supports. |
| 7 | Nomad Mk4 front cover (screen side) | 1 | PETG or PLA | Slides on front-to-back; snap fit (can be glued). |

## Software (all free)

| Tool | Purpose |
|---|---|
| [Arduino IDE](https://www.arduino.cc/en/software) | Flash the firmware |
| [FAT32Format GUI](https://fat32format-gui.en.lo4d.com/windows) | Format >32 GB cards as FAT32 on Windows |
| [HandBrake](https://handbrake.fr) | Compress video (Fast 480p preset recommended) |
| [Nomad Tools](https://github.com/Jstudner/Nomad-Tools) | Optional — prep offline Wikipedia/ZIM archives |
| [SquareLine Studio](https://squareline.io) | Optional/advanced — edit the device's on-screen UI |

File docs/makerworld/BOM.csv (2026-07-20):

Item | Part | Qty | Required | Notes | Link
1 | Waveshare ESP32-S3 Dev Board, 1.47" LCD version | 1 | Yes | Only supported board; Wi-Fi + display + SD slot + USB-A on one PCB | https://amzn.to/4ktB6oT
2 | microSD card 16-128 GB (up to 2 TB supported), Class 10/U1+ | 1 | Yes | FAT32 format required; fast card = better performance | https://amzn.to/44tM1c4
3 | USB power source (port, charger, or power bank) | 1 | Yes
4 | microSD extender (case-compatible length) | 1 | No | Card access from back of case without disassembly; reduces heat exposure | https://amzn.to/45IWIJz
5 | Thermal pad or paste (small) | 1 | No | Between ESP32-S3 chip and shell; air cooling works fine without
6 | Printed: Nomad Mk4 case body | 1 | Yes | PETG recommended (heat), no supports
7 | Printed: Nomad Mk4 front cover | 1 | Yes | Slides on front-to-back, snap fit

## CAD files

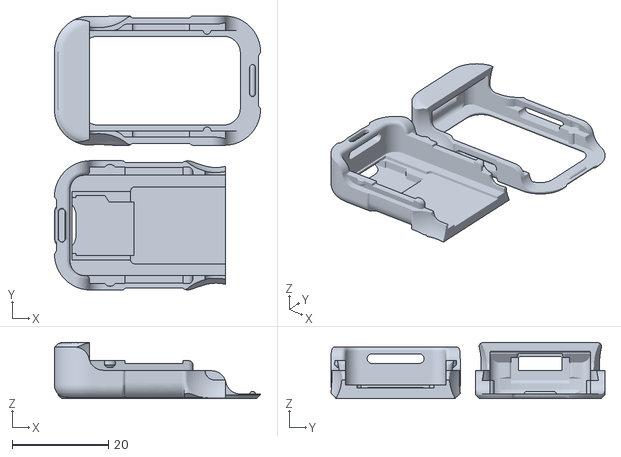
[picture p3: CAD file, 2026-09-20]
NomadCasev30_USB-C.stl
42.8 x 56.8 x 11.7

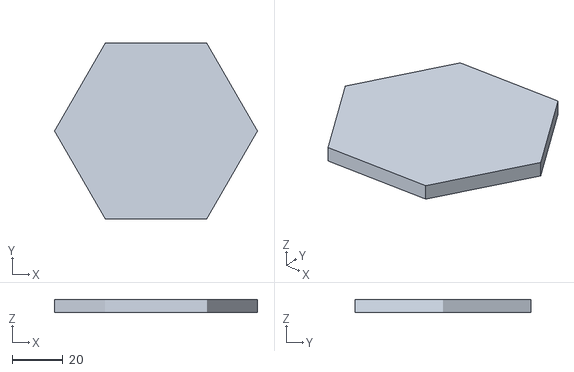
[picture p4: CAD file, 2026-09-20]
SD_Card_Template/Workshop/Hex Coaster 80mm.stl
80.0 x 69.3 x 5.00

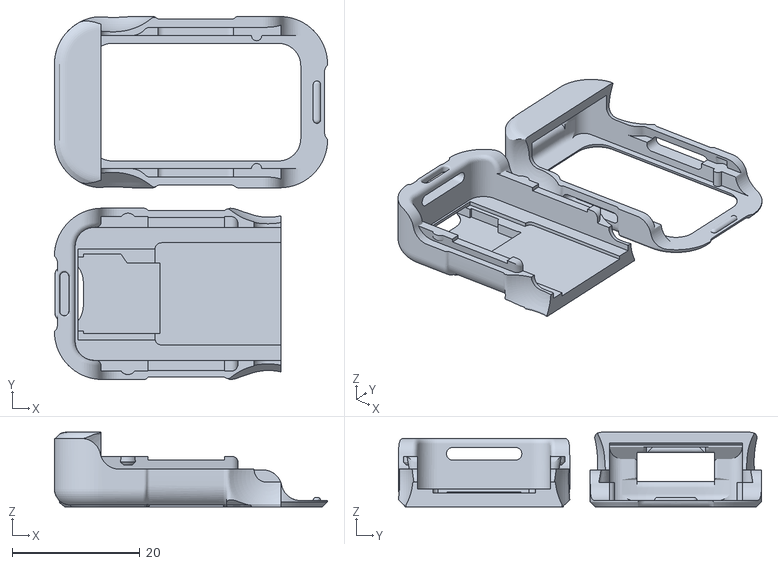
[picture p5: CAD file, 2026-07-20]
NomadCasev30.stl
42.8 x 56.8 x 11.7

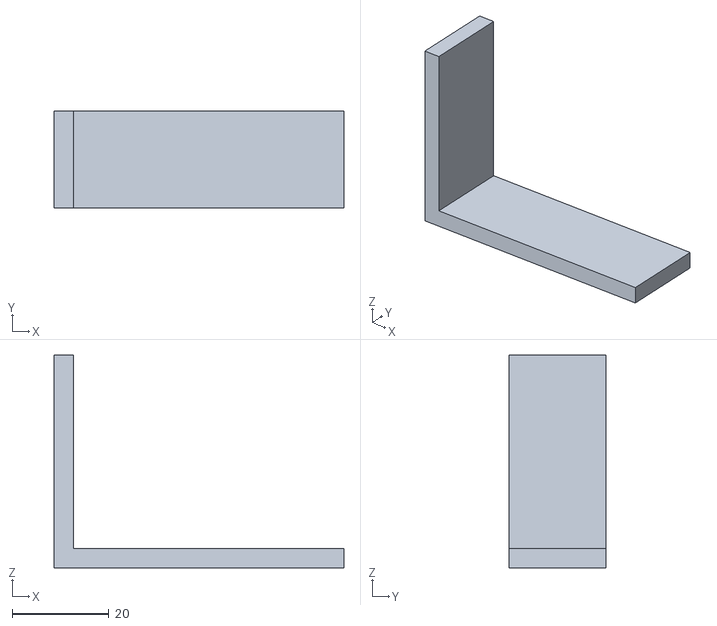
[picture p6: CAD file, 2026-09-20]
SD_Card_Template/Workshop/L Bracket 60mm.stl
60.0 x 20.0 x 44.0

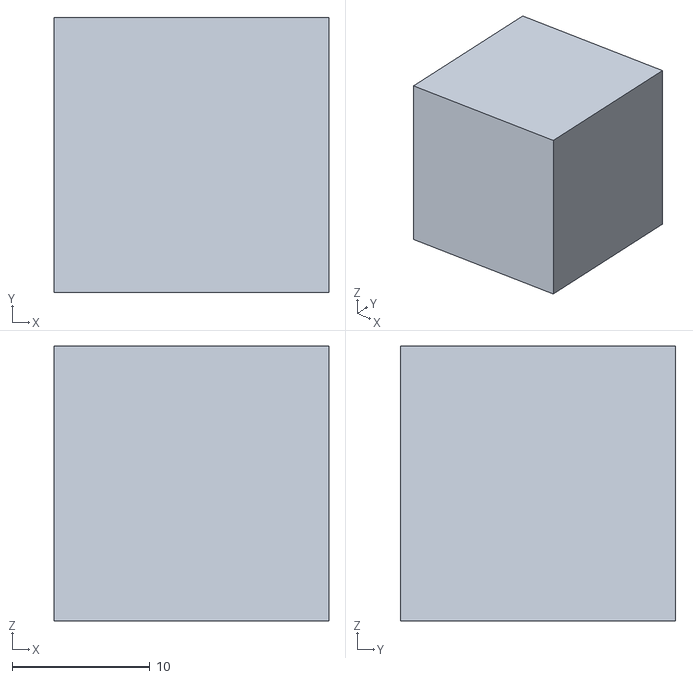
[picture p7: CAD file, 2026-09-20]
SD_Card_Template/Workshop/Calibration Cube 20mm.stl
20.0 x 20.0 x 20.0

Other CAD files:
SD_Card_Template/Archive/.nomad-zim/words-0.skp
SD_Card_Template/Archive/.nomad-zim/words-1.skp
SD_Card_Template/Archive/.nomad-zim/words-2.skp
SD_Card_Template/Archive/.nomad-zim/words-3.skp
SD_Card_Template/Archive/.nomad-zim/words-4.skp
SD_Card_Template/Archive/.nomad-zim/words-5.skp
SD_Card_Template/Archive/.nomad-zim/words-6.skp
SD_Card_Template/Archive/.nomad-zim/words-8.skp
SD_Card_Template/Archive/.nomad-zim/words-a.skp
SD_Card_Template/Archive/.nomad-zim/words-b.skp
SD_Card_Template/Archive/.nomad-zim/words-c.skp
SD_Card_Template/Archive/.nomad-zim/words-d.skp
SD_Card_Template/Archive/.nomad-zim/words-e.skp
SD_Card_Template/Archive/.nomad-zim/words-f.skp
SD_Card_Template/Archive/.nomad-zim/words-g.skp
SD_Card_Template/Archive/.nomad-zim/words-h.skp
SD_Card_Template/Archive/.nomad-zim/words-i.skp
SD_Card_Template/Archive/.nomad-zim/words-j.skp
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

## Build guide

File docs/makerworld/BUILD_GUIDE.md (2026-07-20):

# Jcorp Nomad — Simple Build Guide

Total time: about an hour (plus print time). No soldering, no wiring.

**Golden rule: test everything BEFORE snapping the case together.** The snap tabs weaken a little each time you open it, and the screen is fragile.

---

## Step 1 — Print the case

- **Material:** PETG recommended (the board runs warm); quality PLA is fine too
- **Supports:** none · **Layer height:** 0.2 mm · **Infill:** 15%+
- If your printer's tolerances run tight, print at **101% scale** and size down if loose
- Parts: case body + front screen cover (slides on front-to-back)

## Step 2 — Flash the firmware

1. Download/clone the repo: https://github.com/Jstudner/jcorp-nomad — you need **everything** in `firmware/JcorpNomadProject/`
2. Install [Arduino IDE](https://www.arduino.cc/en/software)
3. **File → Preferences → Additional Board Manager URLs**, add:
   `https://raw.githubusercontent.com/espressif/arduino-esp32/gh-pages/package_esp32_index.json`
4. **Tools → Board → Board Manager** → install **"esp32 by Espressif Systems"**
5. Plug the board into a USB port (it plugs in like a flash drive) and set under **Tools**:

   | Setting | Value |
   |---|---|
   | Board | ESP32S3 Dev Module |
   | Port | your COM port |
   | USB CDC On Boot | Enabled |
   | Flash Size | 16MB (128Mb) |
   | Partition Scheme | 16MB Flash (3MB APP/9.9MB FATFS) |
   | PSRAM | OPI PSRAM |
   | Upload Speed | 921600 |
   | USB Mode | USB-OTG (TinyUSB) |

6. **Tools → Manage Libraries**, install these **exact versions**:
   - ArduinoJson (Benoit Blanchon) **v7.3.0**
   - Async TCP (ESP32Async) **v3.4.7**
   - ESP Async WebServer (ESP32Async) **v3.7.1**
   - LVGL (kisvegabor) **v8.3.10**
   - SdFat (Bill Greiman) **v2.3.0**
7. Open `JcorpNomadProject.ino` and click **Upload**. Done when you see "Done uploading."

> **Stuck in a bad state / board not detected?** Enter flash mode manually: hold **BOOT**, press and release **RESET**, then release **BOOT**.
> **"No such file or directory" library errors?** Wrong library version — clean your Arduino libraries folder and reinstall just the ones above.

## Step 3 — Prepare the SD card

1. Format the card as **FAT32** (Windows won't do >32 GB cards natively — use the free [FAT32Format GUI tool](https://fat32format-gui.en.lo4d.com/windows), allocation size 32K, quick format ✅)
2. Copy everything from the repo's `SD_Card_Template/` folder to the card root
3. Add your media:

```
/Movies   Interstellar.mp4 + Interstellar.jpg   (poster = same name, .jpg)
/Shows    /The Office/S01E01 - Pilot.mp4 ... + The Office.jpg
/Music    mp3/flac/wav — artist/album/playlist folders all work
/Books    PDF, EPUB, CBZ/CBR comics, MP3 audiobooks + matching .jpg covers
/Gallery  photos and video clips
/Files    anything you want to share
```

**Media tips:**
- FAT32 limit: no single file over **4 GB**
- Compress video with [HandBrake](https://handbrake.fr): **Fast 480p preset, H.264, RF 22–24, "Web Optimized" checked, burn in subtitles** — smaller files = more simultaneous streams
- Name episodes `S01E01 - Title.mp4` — everything sorts alphabetically
- Get poster art from [themoviedb.org](https://www.themoviedb.org)
- Offline Wikipedia/ZIM archives need prep with [Nomad Tools](https://github.com/Jstudner/Nomad-Tools) first — you can't just drop a .zim on the card

## Step 4 — First boot & test

1. Insert the SD card, plug into USB power
2. Connect a phone/laptop to Wi-Fi **`Jcorp_Nomad`**, password **`password`**
3. The media menu should open automatically (captive portal); if not, browse to `http://nomad.local/` or `192.168.4.1`
4. Open the **gear icon → Library Index → Full Scan Now** and let it index (a few minutes for big libraries)
5. Play a video. If it streams, you're golden.

## Step 5 — Assemble the case

- Start from the **USB side**, press down gently, and slide the cover front-to-back — the far end from the USB goes on last
- **Be gentle around the screen** — the case exists to protect it, don't let it do the breaking
- Buttons stay exposed, so you never need to open it again for firmware updates

### Heat notes
The board runs warm under load — that's normal, air cooling is fine (all testing was done air-cooled). Optional: a small thermal pad between the ESP32-S3 chip and the shell, and the SD extender keeps the card away from the heat.

---

**Problems?** Check the [GitHub discussions](https://github.com/Jstudner/jcorp-nomad/discussions) — most issues are already documented — or drop a comment.

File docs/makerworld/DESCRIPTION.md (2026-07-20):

# Jcorp Nomad — Pocket Offline Media Server (ESP32-S3)

**A portable, offline media server in a thumbdrive form factor.** Nomad creates its own Wi-Fi hotspot and streams movies, shows, music, books, comics — even full offline Wikipedia — to any phone, tablet, or laptop nearby. No internet, no app, no accounts. Just connect and play.

This is the 3D-printed case + full build for the open-source **Jcorp Nomad Mk4** project. If you can plug in a USB cable and follow instructions, you can build one — the whole build takes under an hour and the parts cost about $20–30.

![Cover image — NomadCoverMK4v2.png]

---

## What it does

- Creates a local Wi-Fi hotspot (captive portal — devices auto-open the media menu)
- Streams to **multiple users at once**, each watching their own thing
- **Movies & Shows** with resume playback, poster art, and season folders
- **Music** with playlists, shuffle, and a live queue
- **Books**: PDF, EPUB, comics (CBZ/CBR), and MP3 audiobooks
- **Offline Wikipedia** and other ZIM archives, with fast search (Mk4)
- Photo gallery, general file sharing, and a full admin panel
- 28 built-in themes + dark mode
- Runs entirely off a microSD card — no soldering, no wiring, no assembly beyond the case

## The case (Mk4)

Slides together **front-to-back** so there's never pressure on the fragile screen (the #1 cause of broken displays on the old design). The buttons stay exposed, so you can flash firmware or reboot without opening it up.

This case is a remix of [ESP32 C6 with LCD Screen Enclosure Case](https://makerworld.com/en/models/2121443-esp32-c6-with-lcd-screen-enclosure-case) by [Adrian](https://makerworld.com/en/@user_1765744671) — full credit for the original design.

## What you need (full BOM in the files)

| Part | Notes |
|---|---|
| Waveshare ESP32-S3 Dev Board, **1.47" LCD version** | The only board Nomad targets — it's the whole computer |
| microSD card, 16–128 GB, Class 10/U1+ | FAT32. Bigger works (up to 2 TB) |
| USB power source | Any USB-A port or charger |
| SD card extender *(optional)* | Lets you swap the card without opening the case |
| ~10–15 g of filament | PETG recommended — the board runs warm |

## Print settings

- **Material:** PETG strongly recommended (device gets warm under load); quality PLA works
- **Layer height:** 0.2 mm · **Walls:** 2+ · **Infill:** 15%+
- **Supports:** none needed
- Snap-fit tolerances: if your printer runs tight, scale to **101%** and adjust down from there

## Setting it up (full guide in the files)

1. Print the case
2. Flash the firmware with Arduino IDE (settings + library versions in the build guide)
3. Format the SD card FAT32, copy the SD template from GitHub, add your media
4. Assemble the case — **after** testing everything works
5. Connect to Wi-Fi `Jcorp_Nomad` (password: `password`) and enjoy

## Links

- **Source code, firmware, and SD template:** https://github.com/Jstudner/jcorp-nomad
- **Step-by-step Instructable:** https://www.instructables.com/Jcorp-Nomad-Mini-WIFI-Media-Server/
- **Prebuilt units** (if DIY isn't your thing): https://nomad.jcorptech.net
- **Support the project:** https://ko-fi.com/jcorptech

Fully open source under **CC BY-NC-SA 4.0**. Firmware and web UI are actively developed — flash the latest code any time to get new features. Featured on [Hackaday](https://hackaday.com/2025/07/13/jcorp-nomad-esp32-s3-offline-media-server-in-a-thumbdrive/).

*Built something with it? I'd love to see it — drop a comment or a build photo.*

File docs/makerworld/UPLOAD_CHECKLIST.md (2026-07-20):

# MakerWorld Upload Checklist

## Post it as a REMIX
The Mk4 case is derived from [ESP32 C6 with LCD Screen Enclosure Case](https://makerworld.com/en/models/2121443-esp32-c6-with-lcd-screen-enclosure-case) by Adrian. When uploading, use MakerWorld's **"Remix" flow from that model page** (or link it as the remix source in the upload form) — that handles attribution properly and keeps you compliant with the original's license. Check the original model's license tag before picking yours; a remix must carry a compatible license.

- Suggested license: **CC BY-NC-SA 4.0** (matches the Nomad repo), if the original allows it.

## Files to upload
- [ ] Case 3MF / print profile — from repo `docs/`: `NomadFullTest.3mf` (plate) — verify it's the current Mk4 parts before upload
- [ ] `AssembledFullTest.3mf` / `AssembledFullTestsingle.3mf` — assembled-view variants, decide which is the print plate vs. display model
- [ ] Consider exporting clean per-part STLs with real names (e.g. `NomadMk4_Body.stl`, `NomadMk4_Cover.stl`) — MakerWorld shows filenames to users
- [ ] `BOM.csv` / `BOM.md` (attach as project files)
- [ ] `BUILD_GUIDE.md` content → paste into the MakerWorld "Assembly/Guide" or description section

## Images (MakerWorld wants several; real photos rank better than renders)
- [ ] Cover: `NomadCoverMK4v2.png` (repo root)
- [ ] Exploded view: `NomadMk4Explode.png`
- [ ] Screen close-up: `NomadNewScreen.png`
- [ ] Real photo of the assembled unit in hand / plugged into a power bank
- [ ] Screenshot of the web UI on a phone (menu + a movie playing)
- [ ] Photo of the printed parts on the plate

## Description
- Paste `DESCRIPTION.md` → fix the image placeholder, verify all links.
- ⚠️ **Affiliate links:** the BOM uses your Amazon affiliate links (`amzn.to/...`). MakerWorld has restrictions on external/affiliate links in descriptions — check current policy; safest is plain product names in the description and affiliate links only on GitHub/Instructables.
- Category suggestion: Electronics → Gadgets. Tags: `esp32`, `esp32-s3`, `media-server`, `offline`, `wifi`, `travel`, `camping`, `open-source`.

## Print profile settings (for the profile upload)
- PETG, 0.2 mm layer, 2+ walls, 15% infill, no supports
- Note in profile description: scale 101% if snap fit is too tight

## Cross-link when live
- [ ] Add the MakerWorld model link to the GitHub README ("Mk4 case files" section currently just says "in this repo")
- [ ] Add it to the Instructable's Case step
- [ ] `[ADD MAKERWORLD LINK]` placeholders anywhere you keep project links (jcorptech.net, Ko-fi page)

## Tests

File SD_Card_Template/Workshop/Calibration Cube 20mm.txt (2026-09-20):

The classic first print. 20 x 20 x 20 mm.

Print at 0.2mm layers, no supports. Measure the sides with calipers
afterwards: all three should read 20.0mm. If X or Y is off, check belt
tension; if Z is off, check your first layer squish.

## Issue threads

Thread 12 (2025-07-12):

ESPAsyncWebServer.h: No such file or directory

brock, 2025-07-12:
Building in Arduino IDE is throwing this error:

```
~/jcorp-nomad/firmware/JcorpNomadProject/JcorpNomadProject.ino:4:10: fatal error: ESPAsyncWebServer.h: No such file or directory
    4 | #include "ESPAsyncWebServer.h"
      |          ^~~~~~~~~~~~~~~~~~~~~
compilation terminated.
exit status 1

Compilation error: ESPAsyncWebServer.h: No such file or directory
```

Jstudner, 2025-07-12:
Howdy! This is an easy fix! go [here](https://github.com/Jstudner/jcorp-nomad/releases/tag/library) and download /unzip the library folder. Point Arduino at those, or clean out your library files and place these there. (on windows its usually C:\Users\<User>\Documents\Arduino\libraries

also if you don't have a libraries file yet just drop the extracted folder in Arduino and it should fix your issue!

Vandypointe2, 2025-08-16:
> Howdy! This is an easy fix! go [here](https://github.com/Jstudner/jcorp-nomad/releases/tag/library) and download /unzip the library folder. Point Arduino at those, or clean out your library files and place these there. (on windows its usually C:\Users<User>\Documents\Arduino\libraries
>
> also if you don't have a libraries file yet just drop the extracted folder in Arduino and it should fix your issue!

So I tried to do this, but when I drop the extracted folder in, it continually just restarts and show the projects files as jumbled. I am not really sure how to fix the libraries as I have tried to import as a zip, and it tells me that it is not a library zip correctly formatted, and I have not been able to manually place it in the sketch folder location as a libraries folder. Do you have a tutorial video I could follow in some way for the firmware flashing portion of all of this?

Jstudner, 2025-08-16:
Howdy! If you use the latest version of the code from GitHub I actually fixed the library issue all together. When did you download the actual code from GitHub? Let me know and I will help you troubleshoot!

Jstudner, 2025-08-16:
Actually I know exactly what the issue is, I just tested it my bad 😅. Still super simple you need to manually grab a few library's. Go to the library manager and you can add them there. I'll update the docs tonight with the exact versions.

Vandypointe2, 2025-08-16:
Honestly I know nothing about any of this, so its all new, but looking at the project files its apparent that its way over my head. Fingers crossed I can get it working.

Jstudner, 2025-08-16:
I should be able to get you through it without too much more trouble. Trying to make it as beginner friendly as possible so the feedback certainly helps. (Also YouTube video tutorial coming soon editing is hard 😅)

Here is what you need to get it running. On the left side panel of Arduino IDE there are 5 icons, the middle one looks like books and when clicked says "library manager"

You need to search for and install the following library's and then it should compile fine

"ArduinoJson" by Benoit Blanchon v7.3.0
"Async TCP" by ESP32Async v3.4.7
"ESP Async Webserver" by ESP32Async v 3.7.1
"LVGL" by kisvegabor V8.4.0

Pay attention to the versions, some will work but best to keep the same ones. Install each and then try compiling again, should fix your problem!

Vandypointe2, 2025-08-17:
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

I was able to get it all flashed and running. Changed the SSID and other settings. I  put an MP4 into the SD storage in the movie folder and it shows in the admin files view, just like the sample videos, but in the movies area of the main menu, there are no types of media in any of the selections, even though I know the board can see it all. Even after gen of the json. I am not sure where I am wrong here.

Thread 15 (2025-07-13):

Impossible to compile

alfem, 2025-07-13:
Hi!

This looks like an amazing project! I used a portable media streamer years ago, in long trips with my little sons. But this DIY solution is really interesting (and portable).

However, I can not compile it. I tried both, main an experimental branches. I moved my usual libraries away and put your zipped libraries in place.

But compile process gives these errors:
```

/prog/jcorp-nomad/firmware/JcorpNomadProject/Display_ST7789.cpp: In function 'void Backlight_Init()':
Display_ST7789.cpp:217:3: error: 'ledcAttach' was not declared in this scope
   ledcAttach(EXAMPLE_PIN_NUM_BK_LIGHT, Frequency, Resolution);
   ^~~~~~~~~~
/prog/jcorp-nomad/firmware/JcorpNomadProject/Display_ST7789.cpp:217:3: note: suggested alternative: 'ledcAttachPin'
   ledcAttach(EXAMPLE_PIN_NUM_BK_LIGHT, Frequency, Resolution);
   ^~~~~~~~~~
   ledcAttachPin

/prog/jcorp-nomad/firmware/JcorpNomadProject/Wireless.cpp: In function 'int ble_scan_number()':
Wireless.cpp:44:51: error: cannot convert 'BLEScanResults' to 'BLEScanResults*' in initialization
   BLEScanResults *foundDevices = pBLEScan->start(5);
                                                   ^
```

The only libraries I have not replaced are the esp32/hardware ones.

Any clue?

Jstudner, 2025-07-14:
Howdy! Glad you are excited about the project! Let me see if I can help. I would start by checking you are using the same Arduino version, it shouldn't matter but I wouldn't be that surprised, I use 2.3.4. Next thing is for the board manager are you using esp32 ver 3.1.3. I havent personaly hit the same error as you before, but it seems like the newer versions use different calls, which is why you get that error. (also double check you setup the tools section correctly for the waveshare board.) let me know if that does the trick, if not ill look into it some more!

Jstudner, 2025-07-14:
any chance you are using a Tdongle board instead of the waveshare one? I just got a similar error trying to work with that board.

Jstudner, 2025-07-15:
Howdy! Check relieses on the main page, as it says in the instructibles the libraries are really specific so best to just download and use the zip included.
https://github.com/Jstudner/jcorp-nomad/releases/tag/library

This has the exact ones to use.

Best of luck! I'll look into the lv_conf next!

weecc-git, 2025-07-15:
Thank you so much. I just copied the lv_config_template from the lvl library and renamed it lv_conf.h and dropped it into the same level as lvl, and that allowed the compile to continue. Thanks again for you work on this project!

Jstudner, 2025-07-15:
Good catch, I will update both of those! I am about to update with a new editable UI for the LCD, so had to change a bunch anyway. Thanks for letting me know!

weecc-git, 2025-07-15:
Final note: I managed to successfully compile and upload the firmware ONLY after setting the Arduino IDE parameter Flash Size to 16MB from the default 4MB. Otherwise the firmware will upload but the device will be locked in a boot loop because the partition topology is incorrect.

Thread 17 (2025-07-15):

[Feature Request] ZIM / Kiwix support

gjgradem, 2025-07-15:
This is an amazing project and i'm soon to build my own! What would make this even more amazing is perhaps adding support for Kiwix / zim files so it not only is an entertainment device, but also a survival device!

Cheers and good luck with this amazing project!

Jstudner, 2025-07-15:
Ill take a crack at this, Really good idea actually!

Jstudner, 2025-07-15:
Ok, yea after looking into it a bit it should be doable, but there are a few things: Fat32 limits the max individual file size to 4gb > zim files can be downloaded in a split format under 4gb each, that being said the support for file splitting looks less than ideal. Any Zim you can download under 4gb will work by default, but you may need to mess around with online tools to split larger ones, and getting full Wikipedia may not be great. Ill be working it it though!

Also going to add a script to the sd card files for running the webserver off a PC so the data isn't stuck on the device if it gets damaged!

Jstudner, 2025-07-15:
I will put a reader for it together, its handled fully in the browser so it might run a bit slow but it will defiantly work to some extent. If I can find a reliable way to split zims I will make a guide! For now I am going to focus on basic functionality, but I think I can just yoink their frontend that already supports slits.

Jstudner, 2025-07-15:
But yes, esp32 only supports fat32, which is nice in some ways, but yea it mostly sucks lol, the bigger brother to this thing is going to run with an ARM based chip, so that will fix like... literally everything

gjgradem, 2025-07-15:
Haha you have a lot of knowledge about these ESP's. Limitations exist and that's fine. Then i think the comment you made about creating basic functionality will be more then fine. I just ordered the ESP and am very curious to see if i can install it! Amazing work man. Thanks :)

Jstudner, 2025-07-18:
That could work, but the issue is that many of my libraries don't work in exfat, its much less common for esp32. not impossible but a lot of work for a minor feature, would possibly need to scratch build some.

As far as file splitting goes it seem like support for that has widely ended. I have seen a few tools, but many complaints about it corrupting files and not being reliable. I am still planning to get some level of ZIM support since it makes sense to have though, and there are way to split files so if I can get it reliable I will post documentation of that too!

Jstudner, 2025-07-29:
ok, I have been doing a bunch of work getting polish done on Nomad so I can update main. after revisiting this for a few hours I have decided I am not going to support kiwix just yet. I can get it to work as long as the files are under 4gb, but I cant get a reliable method for splitting larger files that doesn't break them. I will add support to the bigger version of nomad I am setting up next though! I love the idea, but it shines with a large library and I just cant get that yet.

Closed 2025-07-29.

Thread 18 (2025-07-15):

No display / No WiFi

tylerobara, 2025-07-15:
I have flashed from this repo on my macbook and windows. No errors. I have tried it in a few different USB power bricks and computers and I can never get a wifi network to show up or anything on the display. Any troubleshooting steps or tips for this situation?

Jstudner, 2025-07-15:
Howdy! You can also use Arduino ide (magnifying glass in top right) for serial, sometimes a bit more reliable. that being said could you send a bit more of the serial output? part 3 usually means that the partition scheme is messed up, but it sounds like you already addressed that, you might try enabling "erase all flash before sketch upload" Its a bit above the partition scheme option in tools, that could be the issue. keep me posted, and if you can send me a chunk of the serial output!

Jstudner, 2025-07-15:
this error is showing your chip as only having 4mb of memory not 16: ` exceeds flash chip size 0x400000`
What board are you working with? Might be a weird read error, you might try reseting it by clicking and holding the left button, then clicking the right button and releasing, then releasing the left button (all while powered on).

Jstudner, 2025-07-15:
you might even try setting flash to 4MB (1MB APP / 1.9MB FATFS) and try, wont run well but if it compiles we will know some more

Jstudner, 2025-07-15:
I read that wrong, the one in IDE is going to be 4mb with fatfs (1.2MB APP / 1.5MB FATFS) >>>> not (1 /1.9)

tylerobara, 2025-07-15:
> this error is showing your chip as only having 4mb of memory not 16: ` exceeds flash chip size 0x400000` What board are you working with? Might be a weird read error, you might try reseting it by clicking and holding the left button, then clicking the right button and releasing, then releasing the left button (all while powered on).

Here is the item I got from Amazon: https://www.amazon.com/dp/B0DFTCC1FT?ref=ppx_yo2ov_dt_b_fed_asin_title
"Built-in 512KB SRAM and 384KB ROM, with onboard 16MB Flash and 8MB PSRAM. Onboard 1.47inch LCD display, 172×320 resolution, 262K color"

Jstudner, 2025-07-15:
Try erasing the flash again, it sounds like it got partitioned weird

tylerobara, 2025-07-15:
Maybe it was this, it was set to 4MB 🤦

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

tylerobara, 2025-07-16:
Getting closer, seems like it's starting and crashing:
```
=== ESP32-S3 Captive Portal & SDMMC Server ===
ESP-ROM:esp32s3-20210327
Build:Mar 27 2021
rst:0x3 (RTC_SW_SYS_RST),boot:0x8 (SPI_FAST_FLASH_BOOT)
Saved PC:0x40376be6
SPIWP:0xee
mode:DIO, clock div:1
load:0x3fce2820,len:0x1150
load:0x403c8700,len:0x4
load:0x403c8704,len:0xc24
load:0x403cb700,len:0x30b4
entry 0x403c88b8

=== ESP32-S3 Captive Portal & SDMMC Server ===
ESP-ROM:esp32s3-20210327
Build:Mar 27 2021
rst:0x3 (RTC_SW_SYS_RST),boot:0x8 (SPI_FAST_FLASH_BOOT)
Saved PC:0x40376be6
SPIWP:0xee
mode:DIO, clock div:1
load:0x3fce2820,len:0x1150
load:0x403c8700,len:0x4
load:0x403c8704,len:0xc24
load:0x403cb700,len:0x30b4
entry 0x403c88b8

=== ESP32-S3 Captive Portal & SDMMC Server ===

=== ESP32-S3 Captive Portal & SDMMC Server ===

=== ESP32-S3 Captive Portal & SDMMC Server ===

=== ESP32-S3 Captive Portal & SDMMC Server ===
```
The very first time I was able to scan and find the wifi network but it doesnt seem to stay booted anymore. I'm gonna try another flash.

Jstudner, 2025-07-16:
Yea it's crashing, but still loading it as 4mb so that's the main reason. I think you need to check all of your settings one by one. You need to enable the settings for cleaning / removing flash on load. When I get home in an hourish if you are still stuck I'll send a pic of what it should look like. Also make sure you have the board type set to esp32s3 dev board.

tylerobara, 2025-07-16:
I had arduino side by side with your settings this last time. Ill research some kind of manual partition wipe then re-flash

Jstudner, 2025-07-16:
Best of luck, again keep me posted! Always happy to help!

Jstudner, 2025-07-16:
well, sorry it isn't working for you but I will be around tomorrow to help, I can also call if you need!

Jstudner, 2025-07-19:
Here is the setup, be sure to set it as esp32s3 dev module in settings as well. If you have trouble with library not found errors check the GitHub versions, there is a zip of all my libraries you can replace yours with (you basically must do this). Let me know if it works, happy to help troubleshoot!

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

chrisallick, 2025-07-19:
Ok, I was able to get the basic microsd example working, loading images and what not on the screen. So I know its working. Huh... I am not sure what is going on. I will try your libraries and start over.

Jstudner, 2025-07-20:
Yea 90% of the issues so far have been due to the libraries, download and unzip the "libraries" folder, and then delete your old libraries folder and put this one in its place (or if you do Arduino stuff often just replace everything inside. It's usually in /username/documents/Arduino/libraries on windows

chrisallick, 2025-07-20:
oof i tried your libraries folder and it immediately started puking up errors. i couldn't get it to compile.

Jstudner, 2025-07-20:
Show me what error you got, I can walk you though it. Also happy to do a discord call or something if you need more help!

chrisallick, 2025-07-20:
Ignore, im a moron. I was deleting my libraries folder and just dumping into Arduino folder :) It works haha.

I'd love to figure out how to get it working with updated libraries and not just black box replacing everything, but it is working. It's not playing back my mp4s. And I'll be excited to see it support mkv.

Jstudner, 2025-07-20:
New file support is coming very soon! glad you could get it working! enjoy!

Closed 2025-07-20.

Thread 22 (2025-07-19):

Waveshare ESP32-S3 USB-C Black Screen Issue

daninykh, 2025-07-19:
I was having an issue with the screen being dark, even though I was uploading Waveshare's stock firmware just fine.

I'm not sure if it's because I'm using the USB-C version, but I had to change the pin num for backlight in, "Display_ST7789.h".

It's at the top of the file, originally it was set to 48 but following the waveshare demo has it set to 46.

```
#pragma once
#include <Arduino.h>
#include <SPI.h>
#define LCD_WIDTH   172 //LCD width
#define LCD_HEIGHT  320 //LCD height

#define SPIFreq                        80000000
#define EXAMPLE_PIN_NUM_MISO           -1
#define EXAMPLE_PIN_NUM_MOSI           45
#define EXAMPLE_PIN_NUM_SCLK           40
#define EXAMPLE_PIN_NUM_LCD_CS         42
#define EXAMPLE_PIN_NUM_LCD_DC         41
#define EXAMPLE_PIN_NUM_LCD_RST        39
#define EXAMPLE_PIN_NUM_BK_LIGHT       46   <----- Change this from 48 to 46
#define Frequency       1000         
#define Resolution      10
```

I am using only files as the instructable guide with libraries copied from the instructables as well.

Hope this helps someone!

Jstudner, 2025-07-19:
That is super helpful! Could I get the amazon link or the exact product number? Glad you managed to get it working though! and thank you for the update!

daninykh, 2025-07-19:
https://a.co/d/2PQ3kJo

I choose the USB-C version purely because I thought it looked sleeker lol.

And, no, thank you! I named my SSID "DoomsDay"

Closed 2025-07-19.

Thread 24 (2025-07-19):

Flashed deviced. RGB pixel noise when SD Card inserted.

chrisallick, 2025-07-19:
Ok, I got it compiling and running, but when I put the sd card in hte screen is just random pixels. its just rgb white noise.

serial monitor is spitting this out repeatedly? Any thoughts? without SD card i can see the wifi network.

```
assert failed: tcp_alloc /IDF/components/lwip/lwip/src/core/tcp.c:1854 (Required to lock TCPIP core functionality!)

Backtrace: 0x4037671d:0x3fcbac70 0x4037e77d:0x3fcbac90 0x4038544a:0x3fcbacb0 0x420573a7:0x3fcbadf0 0x4205750d:0x3fcbae10 0x42010bdd:0x3fcbae30 0x4200edfe:0x3fcbae80 0x420056ca:0x3fcbaea0 0x4203b3fb:0x3fcbaf00 0x4037f452:0x3fcbaf20

ELF file SHA256: d9dc8883c

Rebooting...
ESP-ROM:esp32s3-20210327
Build:Mar 27 2021
rst:0xc (RTC_SW_CPU_RST),boot:0x8 (SPI_FAST_FLASH_BOOT)
Saved PC:0x4037b68e
SPIWP:0xee
mode:DIO, clock div:1
load:0x3fce2820,len:0x1150
load:0x403c8700,len:0x4
load:0x403c8704,len:0xc24
load:0x403cb700,len:0x30b4
entry 0x403c88b8

```

chrisallick, 2025-07-19:
Might have found the issue with ESPAsyncWebServer version

chrisallick, 2025-07-19:
https://imgur.com/a/8fAUa8Q

chrisallick, 2025-07-19:
Shoot I thought I had figured it out. I switched board configs to ESP32S3 Dev Module. I was using Waveshare ESP32 S3 1.47LCD (which seemed right) https://www.waveshare.com/wiki/ESP32-S3-LCD-1.47#Resources

Still not working with SD Card inserted.

New configuration: https://imgur.com/a/xf3HsLz

I've also noticed the SSID does not read JCORP_NOMAD

Jstudner, 2025-07-20:
Is the SD card in when you power it? that can cause the first issue. the white noise is usually boot, you can disable that in firmware to an extent. that being said it sounds like an issue with the web system. did you change the default ssid and password? If the password is less than 8 characters you will get pretty much the same issues so that might be it. let me know, I am happy to help get it up and running!

chrisallick, 2025-07-20:
Copying over the entire libraries folder worked. I was disappointed I couldn't get it working with standard library installs, but I think the code base is relying on nuanced branches and patches.

chrisallick, 2025-07-20:
Oh I did change the password and it was only 5 characters! Wow, ok well it is working with your suggested method of copying over libraries folder. Now Im going to start over and try and get it working from scratch with updated libs. This is so cool. I'm so excited.

Jstudner, 2025-07-20:
glad that worked haha, Ima be so real it took a miracle to get the original libraries working, and at this point I think ima just add to the docs requiring people to do it, basically every library takes an exact version.

Enjoy!

Jstudner, 2025-07-20:
> Oh I did change the password and it was only 5 characters! Wow, ok well it is working with your suggested method of copying over libraries folder. Now Im going to start over and try and get it working from scratch with updated libs. This is so cool. I'm so excited.

Its a dumb requirement of the captive portal (for your phone to let it redirect), haven't found a way around it yet sorry!

chrisallick, 2025-07-20:
Im taking your libraries folder, compiling, testing, and deleting down one by one till I get to a diff. At a minimum that will help.

chrisallick, 2025-07-20:
oh im almost positive that is what it is :) hahah

Jstudner, 2025-07-20:
Ain't that just the way it goes 😅

chrisallick, 2025-07-20:
Ok, i moved RGB_Lamp files to the project folder and out of libs. They aren't trackable via the arduino ide.

Libraries required (nothing else in my libraries folder):

Very good:

ArduinoJson 7.4.2 - standard library installed via Arduino IDE - works fine. Deleted your version and overrode it with the library manager version. works ok for me.

Async TCP 3.4.5 - standard library installed via Arduino IDE - works fine.  Deleted your version and overrode it with the library manager version. works ok for me.

ESP Async WebServer 3.7.10 - standard library installed via Arduino IDE - works fine.  Deleted your version and overrode it with the library manager version. works ok for me.

Not as great, but not bad at all:

lvgl 8.3.10 (your version) -> 9.3.0 (latest) - installed via Arduino IDE, copied over the template config file... failed. you're on 8.3.10... can't figure it out. somehow your folder of lvgl doesn't need the config file. but i don't see a flag anywhere in your code that is making that unrequired.

Ah, found the issue. in your lvgl 8.3.10 you added lvgl_config.h in the src folder. Using arduino ide you can install the 8.4.0 standard lib and just copy the lv_conf.h file. works great. so maybe an upgrade would be rewriting the ui stuff to work for 9.3 that would get you fully aligned to Arduino IDE latest maintained lib, but pretty easy fix to just copy over that conf file. Not familiar with this library.

I'll try and fix this. I am not sure how this library works, but should be simple enough to redo the UI with updated calls to new version, but also, who cares.

Ok, so that is it. Moved the rgb lamp files, and then you need 3 standard libraries latest version and 1 augmented old version: lvgl. That should simplify things quite a bit! You only really need that one lvgl thing!

Good stuff, love this project. Gonna keep noodling myself. I have an art project idea :)

Jstudner, 2025-08-02:
ok, I just finished my big polish update rush, now I am working on fixing all the damn library errors haha, thank you for looking into it so much, going to save me so much time!

Closed 2025-07-20.

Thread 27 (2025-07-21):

AP is not set to value specified by WIFI_SSID

mhschmall, 2025-07-21:
WiFi.softAP(WIFI_SSID, WIFI_PASSWORD) does not set the ssid or password that are specified via the definitions. What I get for a ssid is ESP_XXXX.
Im using Arduino IDE 2.3.6 and have set erase all flash prior to download to true.

mhschmall, 2025-07-22:
Setting the password to over 8 chars, reflashing, and a hard reset did the job. Thanks for the pointer.

Jstudner, 2025-07-22:
Happy it was an easy fix! Enjoy!

mhschmall, 2025-07-22:
I was going to suggest adding a comment about this issue to the main ino file and someone else already beat me to the pull request.

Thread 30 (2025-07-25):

Getting an error when trying to flash

llamaburn, 2025-07-25:
Z:\Programs\Nomad\Arduino\jcorp-nomad-main\jcorp-nomad-main\firmware\JcorpNomadProject\JcorpNomadProject.ino:4:10: fatal error: ESPAsyncWebServer.h: No such file or directory
    4 | #include "ESPAsyncWebServer.h"
      |          ^~~~~~~~~~~~~~~~~~~~~
compilation terminated.
exit status 1

Compilation error: ESPAsyncWebServer.h: No such file or directory

Jstudner, 2025-07-25:
Howdy! Easy fix! you need to replace the contents of your library folder with the ones you can download [here](https://github.com/Jstudner/jcorp-nomad/releases/tag/library) It can usually be found at /documents/Arduino/libraries on windows

Closed 2025-07-25.

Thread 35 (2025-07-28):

Feature Request: Internet connectivity

unxplained, 2025-07-28:
Hi,

I was thinking that it would be very useful if the device can connect to a wifi network so that the client device would have internet connectivity.

E.g. hotel wifi > nomad > phone, for the phone to still have internet connectivity while connected to nomad

Thanks

mhschmall, 2025-07-29:
https://techtutorialsx.com/2021/01/04/esp32-soft-ap-and-station-modes/

Jstudner, 2025-07-29:
OK! I have done some research, and for now I don't think this is an option. The article mhshmall linked is useful, but doesn't actually let you route traffic between the two networks, so its not feasible in this case. I looked into modifying it, but it takes too much work for the CPU/RAM to manage while also doing web server stuff. I did also try looking into having the captive portal not grab and redirect every single request (which does allow for you to use mobile data), but I cant get it to work reliably. For now I am going to back burner it, I will defiantly revisit the idea when I build the big version (that should have enough power to properly send packets and use both networks as intended)

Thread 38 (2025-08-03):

case matters with file extensions.

mhschmall, 2025-08-03:
The media generator for gallery files will not recognize capital versions of popular file extensions. For example, image.jpg is indexed while image.JPG is not. A lot of camera's write files with capitalized extensions. This is a quick fix, here is the line I corrected:

#604      ".jpg", ".JPG", ".jpeg", ".png", ".PNG", ".bmp", ".gif",".GIF",

I suppose if you really want to be pedantic, you could provide capitalized versions of every extension, but in my example I just went for the most common examples.

mhschmall, 2025-08-06:
Confirmed.

Closed 2025-08-06.

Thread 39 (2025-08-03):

Feature Request: Need gallery upload button

mhschmall, 2025-08-03:
This new release is amazing. You've put a lot work into it and it shows!

However, the gallery page really needs an upload button. For nominal security, the file to be uploaded should be sanity checked against the  mediaExts list and rejected if it doesnt have a valid extension.

Thanks for all the work.

Jstudner, 2025-08-03:
Ah! They didnt upload due to being empty. I will add placeholder items to them this afternoon and update! Thx for the catch!

Jstudner, 2025-08-03:
This one will take a bit longer since I want to have some level of admin control for it (maybe disable it if the admin user doesn't want people to upload) That being said it would be cool to have. I will also need to have it check the SD card for space as well as the other sanity checks, so I will probably address it when I redo the SD card checks (causes a screen glitch on the LCD every 60 sec as is)

mhschmall, 2025-08-03:
My use case scenario was using nomad-enabled stick as a party hub: your music and play lists are already loaded, any vids you want to show are loaded, drink recipes are loaded in the books section, and gallery was where people could share snaps and vids they took during the party.

Jstudner, 2025-08-03:
That's so awesome, glad you can get some good use out of it! Make sure to get the RGB going haha 😂

Keep me posted, I really like seeing people come up with unique use cases!

Jstudner, 2025-08-03:
I don't think I am going to add this to the production version, but I'll update experimental with it once I get the main branch fixed up!

mhschmall, 2025-08-09:
Looks good except gallery page does not refresh upon upload completion. Page sits there with the status bar at 100%.

Closed 2025-08-08.

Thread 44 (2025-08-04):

Trouble making usb mode work

wasspaul, 2025-08-04:
First off thanks for all the effort on this great project.
I am trying the latest experimental build and can not seem to make the usb mode function.

Anyone else having this issue?

I go to the admin page select USB mode.  I see the device go into usb mode (first with a dim display, then with a brighter one.)   After several seconds the device appears to reboot and goes into normal mode.

Any ideas on what I might be doing wrong would be great.

Thanks for your help.

Below is the serial monitors output.

=== Booting Nomad (debug) ===

=== ESP32-S3 Captive Portal & SDMMC Server ===
WiFi AP started...
Initializing SD Card...
SD Card initialized successfully!
Loading Settings...
[SETTINGS] autoGenerateMedia = false
Starting WiFi with SSID: PAW_Mserve
settings.brightness = 27
[BOOT] autoGenerateMedia (from settings) = false
[BOOT] generate_once.flag = false
[BOOT] Skipping media.json generation.
Web Server started!
User-Agent: Microsoft NCSI
Android device. Serving index.html
User-Agent: Mozilla/5.0 (Windows NT 10.0; Win64; x64; rv:141.0) Gecko/20100101 Firefox/141.0
Android device. Serving index.html
User-Agent: Mozilla/5.0 (Windows NT 10.0; Win64; x64; rv:141.0) Gecko/20100101 Firefox/141.0
Android device. Serving index.html
User-Agent: Mozilla/5.0 (Windows NT 10.0; Win64; x64; rv:141.0) Gecko/20100101 Firefox/141.0
Android device. Serving index.html
User-Agent: Mozilla/5.0 (Windows NT 10.0; Win64; x64; rv:141.0) Gecko/20100101 Firefox/141.0
Android device. Serving index.html
User-Agent: Mozilla/5.0 (Windows NT 10.0; Win64; x64; rv:141.0) Gecko/20100101 Firefox/141.0
Android device. Serving index.html
User-Agent: Mozilla/5.0 (Windows NT 10.0; Win64; x64; rv:141.0) Gecko/20100101 Firefox/141.0
Android device. Serving index.html
User-Agent: Mozilla/5.0 (Windows NT 10.0; Win64; x64; rv:141.0) Gecko/20100101 Firefox/141.0
Android device. Serving index.html
User-Agent: Mozilla/5.0 (Windows NT 10.0; Win64; x64; rv:141.0) Gecko/20100101 Firefox/141.0
Android device. Serving index.html
User-Agent: Mozilla/5.0 (Windows NT 10.0; Win64; x64; rv:141.0) Gecko/20100101 Firefox/141.0
Android device. Serving index.html
User-Agent: Mozilla/5.0 (Windows NT 10.0; Win64; x64; rv:141.0) Gecko/20100101 Firefox/141.0
Android device. Serving index.html
>>> /enterUsb handler hit
ESP-ROM:esp32s3-20210327
Build:Mar 27 2021
rst:0xc (RTC_SW_CPU_RST),boot:0x8 (SPI_FAST_FLASH_BOOT)
Saved PC:0x4037af22
SPIWP:0xee
mode:DIO, clock div:1
load:0x3fce2820,len:0x1180
load:0x403c8700,len:0xc2c
load:0x403cb700,len:0x311c
entry 0x403c88b8
=== Booting Nomad (debug) ===
>>> USB mode: mounting SD & starting MSC
>>> USB mode: mounting SD & starting MSC

Note after here I dont get serial output.  best I can tell the PC is in usb mode but the esp is not.

Im running on a windows 10 PC

wasspaul, 2025-08-04:
Thanks for the super quick response.  For me, with USB OTG it looks like its working.  I have not tested it with traffic yet but in a first look I can see it in the file explorer.   I did take a long time to show up in the windows system but yeah its working!

Thanks again.

Jstudner, 2025-08-04:
Yea, I am still working on improving the mount time, but I think to make any real improvement on USB mode I will need to switch to expressif IDE instead of Arduino. Not exactly sure why but the online people say it will make files go faster.

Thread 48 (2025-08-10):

ESP32 BLE error

brentdcarlson, 2025-08-10:
In file included from P:\Arduino\jcorp-nomad-main\firmware\JcorpNomadProject\Wireless.h:3,
                 from P:\Arduino\jcorp-nomad-main\firmware\JcorpNomadProject\Wireless.cpp:1:
p:\Arduino\Sketches\libraries\ESP32_BLE_Arduino\src/BLEDevice.h:12:10: fatal error: esp_gap_ble_api.h: No such file or directory
   12 | #include <esp_gap_ble_api.h> // ESP32 BLE
      |          ^~~~~~~~~~~~~~~~~~~
compilation terminated.
exit status 1

Compilation error: exit status 1

Closed 2025-08-10.

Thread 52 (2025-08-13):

Games Emulation Option / Library

Jstudner, 2025-08-13:

mhschmall, 2025-08-13:
I personally think serving rom's and emulation is a dog whistle for lawyers.

Jstudner, 2025-08-13:
> I personally think serving rom's and emulation is a dog whistle for lawyers.

Well that's a terrifying thought. But actually quite a valid point. I forget you can't buy ROMs 😅.

For now I will stick with HTML games anyway since I don't have a good method for testing emulation anyway.

MMagTech, 2025-08-13:
I understand the legality of this from your point. If for some reason you implement it would be epic from an already awesome piece of software. Think you’d be covered though from a legality standpoint since the roms wouldn’t be supplied.

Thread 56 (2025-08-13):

New Video Player

Jstudner, 2025-08-13:
By integrating a lightweight JavaScript player like Video.js, Nomad could offer richer playback features than the default browser video element. This would add cleaner controls, broader format compatibility, and built-in support for multiple subtitle tracks (VTT) and audio track switching, making it easier to watch content in different languages or with captions.

In addition, the playback system could be paired with an improved browser-side caching method. By saving the last range requests in the browser’s storage, Nomad could “remember” the playback position for the last 3–5 videos watched, allowing users to quickly resume without manually scrubbing back to where they left off. This would make the experience feel more like a full-fledged streaming service, even while fully offline and without ever having a sign in page (since it saves to the browser not nomad).

Jstudner, 2025-09-16:
After further testing the inbrowser system can do subs, and supports most video format, so for simplity I see no reason to include a js library / further complicate the system

Closed 2025-09-16.

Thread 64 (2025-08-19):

Board Compatability - from Waveshare to goouuu esp32-s3

GitPIrate2025, 2025-08-19:
Essentially bought the wrong board for this project by accident but decided to go ahead and try to get it working. The original Gen 1 firmware required very little changes to get the server up and running.

The Goouuu Board is a 1 bit board and its pin allocation is different. As such the following changes were made -

// SD card pinout for Goouuu esp32s3 CAM
#define SD_CLK_PIN 39
#define SD_CMD_PIN 38
#define SD_D0_PIN 40
//#define SD_D1_PIN 18
//#define SD_D2_PIN 17
//#define SD_D3_PIN 21

and

   // Initialize SD card
    Serial.println("Initializing SD Card...");
    if (!SD_MMC.setPins(SD_CLK_PIN, SD_CMD_PIN, SD_D0_PIN)) {
        Serial.println("ERROR: SDMMC Pin configuration failed!");
        return;
    }

this ensures the board runs in 1 bit mode and listens to the correct lanes.

doing this alone allows the Goouuu board to flash and is perfectly functional. (though processing power is being used to run an LCD that is not there)

Problem occurs when trying to use experimental firmware or the new folded firmware main.

changes made

the changes above are replicated in the new firmware but also the RGB_lamp.h function also had to be disabled. This is due to the fact that it uses pin 38 and 40 which the Goouuu needs for SD.  Muting it and its relative functions in code allows the board to flash.

However, this results in an apparent boot loop. I believe the watchdog is being triggered but honestly, I have no idea. This is my first dip in coding in general let alone working with ESP hardware. I'm a quick learner but not that quick.

The error is shown here -

ESP-ROM:esp32s3-20210327
Build:Mar 27 2021
rst:0xc (RTC_SW_CPU_RST),boot:0x9 (SPI_FAST_FLASH_BOOT)
Saved PC:0x40376789
SPIWP:0xee
mode:DIO, clock div:1
load:0x3fce2820,len:0x1180
load:0x403c8700,len:0xc2c
load:0x403cb700,len:0x311c
entry 0x403c88b8
Set Backlight parameters in the range of 0 to 100

Set Backlight parameters in the range of 0 to 100
E (14428) task_wdt: Task watchdog got triggered. The following tasks/users did not reset the watchdog in time:
E (14428) task_wdt:  - IDLE0 (CPU 0)
E (14428) task_wdt: Tasks currently running:
E (14428) task_wdt: CPU 0: SDScan
E (14428) task_wdt: CPU 1: IDLE1
E (14428) task_wdt: Aborting.
E (14428) task_wdt: Print CPU 0 (current core) backtrace

Backtrace: 0x420f0f0e:0x3fcc8730 0x4201da81:0x3fcc8750 0x42001c35:0x3fcc8770 0x42001cfd:0x3fcc87a0 0x42001d89:0x3fcc87c0 0x42010f85:0x3fcc9d70 0x420ef699:0x3fcc9d90 0x42025825:0x3fcc9dc0 0x420262dd:0x3fcc9e90 0x420389aa:0x3fcc9f10 0x4200946e:0x3fcc9f40 0x4037e789:0x3fcc9f60

this repeats infinitely.

[JcorpNomadProject_MODIFIED.txt](https://github.com/user-attachments/files/21849791/JcorpNomadProject_MODIFIED.txt)

A copy of the code I have modified is also included.

Jstudner, 2025-08-19:
Howdy! Based on the error it looks like it's getting stuck trying to talk to the SD card. I will take a look through the code when I am home, but check the pins carefully on the actual board. 1-bit mode is also likely causing an issue, something else in my code might expect it though I will have to check, not sure off the top of my head.

GitPIrate2025, 2025-08-19:
thanks man! look I really appreciate you even bothering to look into it. This is such a cool project, and I would love to be able to use all the new features.

GitPIrate2025, 2025-09-10:
Hey mate, thanks so much for taking the time to troubleshoot. I have had a stab or two at it but could not make much headway. Good to know im in with a chance in the next update maybe.

also all the new features your managing to cram into this project is insane. One this i was trying to do is hookup a 2.5" hdd to my board. its has OTG support. I managed to get it to recognize the drive so far but not load from it.I will provide code when its all working.

Jstudner, 2025-09-10:
I actually might be able to give you a tip on that end! It's likely not picking it up due to being exfat. The chip firmware esp32 comes with only works with fat32 drives. There is a workaround using expressifs ide, but I didn't want to complicate the tutorial as it's less friendly than Arduino. I am working on modifying the actual source files though so at some point I should be able to have exfat support. If you can convert the drive to fat32 (untested but fat32 format will probably do that) you may have better luck.

One of the things I am including on the chonky nomad (this thing is gonna take for fricking ever I keep making it more complicated) is a USB A female port that can take USB hard drives so you can have much larger / modular expandable storage.

Excited to see if you can get this feature working, I would love to add it to the main project if it's successful! 😁

Jstudner, 2025-09-10:
also I didnt consider it when I first looked at your code, but its likely not the initial start of the SD card, but the sd scan task thats causing the crash, if you wanted to try anything deleting that function may fix it. This should be fixed in the new version (system runs in little chunks now) but to check you can try running the code without the scan task.

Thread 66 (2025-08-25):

exceeds flash chip size 0x400000

emptywill, 2025-08-25:
I'm probably doing something wrong, pretty sure I followed your guide properly, I have copied your Arduino library in my library folder.
I get this from the Serial Monitor after flashing firmware:

entry 0x403c88b8
E (29) flash_parts: partition 3 invalid - offset 0x310000 size 0x300000 exceeds flash chip size 0x400000
E (30) boot: Failed to verify partition table
E (31) boot: load partition table error!
ESP-ROM:esp32s3-20210327
Build:Mar 27 2021
rst:0x3 (RTC_SW_SYS_RST),boot:0x8 (SPI_FAST_FLASH_BOOT)
Saved PC:0x403ccf85
SPIWP:0xee
mode:DIO, clock div:1
load:0x3fce2820,len:0x1180
load:0x403c8700,len:0xc2c
load:0x403cb700,len:0x311c
entry 0x403c88b8

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

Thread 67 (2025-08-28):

Page content does not update due to caching

gwenvador, 2025-08-28:
When accessing the movies page after a new upload, changes to content are not reflected immediately. The browser seems to serve a cached version of the page and data. The only way to see updates reliably is to open the page in a new incognito window.
Is that on the user browser or could it be done on the server?

Jstudner, 2025-08-30:
The new experimental version (I'm so close to releasing this damn thing I've been doing stability fixes for a week) should fix this, it replaced the default caching system with a smart one that asks the backend if anything changed, also keeps track of watch progress in cache so you can resume per device.

Jstudner, 2025-09-08:
ok, I am still doing stupid stability fixes but I got this working fairly well. Need to add it to all of the pages, but I can have the frontend reference the index on load and remove items that are not there anymore / manualy grab new items without fully wipeing out the cache now. should work quite nicely.

Jstudner, 2025-09-16:
ok, this is sorta fixed. I am not going to close #67 yet, but the experimental branch has the basic of this functionality and I will be making improvments to it. main issue is it slows the page loading, I need to set it up to cache the info like before, but then after scanning update the page in a non-blocking way (spots differences and edits grid without effecting the existing entrys)

Robin-Sch, 2025-09-16:
Wow, thanks a lot man. Your work is highly appreciated

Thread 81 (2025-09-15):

text section exceeds available space in board

ethanocurtis, 2025-09-15:
when trying to flash the board i get the following:

Sketch uses 1423619 bytes (108%) of program storage space. Maximum is 1310720 bytes.
Global variables use 127052 bytes (38%) of dynamic memory, leaving 200628 bytes for local variables. Maximum is 327680 bytes.
Sketch too big; see https://support.arduino.cc/hc/en-us/articles/360013825179 for tips on reducing it.
text section exceeds available space in board

Compilation error: text section exceeds available space in board

Jstudner, 2025-09-15:
You have to check the board options, your flash size is set to 4mb not 16mb so it thinks its exceeding the size. check the exact settings needed on the instructibles.

ethanocurtis, 2025-09-16:
this worked! however my browser is not redirecting me to the home screen and on the screen the sd card logo isnt ticked on like hte wifi logo, i did format to fat32 with the provded folder structure. its a 256gb sd card.

Jstudner, 2025-09-16:
what does the serial output say? Its likley not mounting the card for one reason or another

Jstudner, 2025-09-16:
Enjoy!! Hope you get good use out of it! 😁

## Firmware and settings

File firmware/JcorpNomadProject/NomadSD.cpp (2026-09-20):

//<!-- Version 4.6 -->
// NomadSD.cpp - exFAT + FAT32 SD support: SdFat on the ESP32-S3 SDMMC host,
// wrapped in the Arduino fs::FS interface. See NomadSD.h for the why.
//
// Layering:
//   sdmmc_host driver (IDF, same peripheral + pins SD_MMC used)
//     -> SdMmcBlockDev (FsBlockDeviceInterface, raw sectors)
//       -> FsVolume (SdFat: auto-detects exFAT / FAT32 / FAT16)
//         -> NomadFSImpl / NomadFileImpl (fs::FSImpl / fs::FileImpl)
//           -> fs::FS "NomadSD" (drop-in for SD_MMC via #define)
//
// Thread safety: SdFat is not reentrant and the card is touched from async_tcp,
// the index workers and the streaming task, so every entry point takes one
// recursive mutex. This replaces the FATFS FF_FS_REENTRANT volume lock.

// SdFat first: its FILE_READ/FILE_WRITE macros clash with the ones in the core's
// FS.h. SdFat's are undef'd below; this file spells out oflags and mode strings.
#include <SdFatConfig.h>  // top-level include so the IDE/arduino-cli pull in the SdFat library
#include "FsLib/FsLib.h"
#include "common/FsBlockDeviceInterface.h"
#undef FILE_READ
#undef FILE_WRITE

#include "NomadSD.h"
#include <FSImpl.h>

#include "driver/sdmmc_host.h"
#include "driver/sdmmc_defs.h"
#include "sdmmc_cmd.h"
#include "esp32-hal-periman.h"
#include "esp32-hal-log.h"
#include "freertos/FreeRTOS.h"
#include "freertos/semphr.h"

using namespace fs;

// ---------------------------------------------------------------- state

static SemaphoreHandle_t s_lock = nullptr;

struct FsLockGuard {
  FsLockGuard() {
    if (s_lock) xSemaphoreTakeRecursive(s_lock, portMAX_DELAY);
  }
  ~FsLockGuard() {
    if (s_lock) xSemaphoreGiveRecursive(s_lock);
  }
};

static sdmmc_card_t s_card;
static bool s_cardInited = false;
static bool s_mounted = false;
static bool s_mode1bit = true;
static int8_t s_pin_clk = -1, s_pin_cmd = -1, s_pin_d0 = -1, s_pin_d1 = -1, s_pin_d2 = -1, s_pin_d3 = -1;

// ---------------------------------------------------------------- block device

class SdMmcBlockDev : public FsBlockDeviceInterface {
public:
  bool isBusy() override {
    return false;  // sdmmc_read/write_sectors block until the card is done
  }
  bool readSector(uint32_t sector, uint8_t *dst) override {
    return readSectors(sector, dst, 1);
  }
  bool readSectors(uint32_t sector, uint8_t *dst, size_t ns) override {
    if (!s_cardInited) return false;
    return sdmmc_read_sectors(&s_card, dst, sector, ns) == ESP_OK;
  }
  bool writeSector(uint32_t sector, const uint8_t *src) override {
    return writeSectors(sector, src, 1);
  }
  bool writeSectors(uint32_t sector, const uint8_t *src, size_t ns) override {
    if (!s_cardInited) return false;
    return sdmmc_write_sectors(&s_card, src, sector, ns) == ESP_OK;
  }
  uint32_t sectorCount() override {
    return s_cardInited ? (uint32_t)s_card.csd.capacity : 0;
  }
  bool syncDevice() override {
    return true;  // writes are synchronous at the driver level
  }
};

static SdMmcBlockDev s_dev;
static FsVolume s_vol;

// ---------------------------------------------------------------- card init

static bool nomadDetachBus(void *) {
  NomadSD.end();
  return true;
}

static bool cardInit(bool mode1bit, int freq_khz) {
  if (s_cardInited) return true;
  if (s_pin_clk < 0 || s_pin_cmd < 0 || s_pin_d0 < 0 || (!mode1bit && (s_pin_d1 < 0 || s_pin_d2 < 0 || s_pin_d3 < 0))) {
    log_e("NomadSD: setPins must be called before begin");
    return false;
  }

  perimanSetBusDeinit(ESP32_BUS_TYPE_SDMMC_CLK, nomadDetachBus);
  perimanSetBusDeinit(ESP32_BUS_TYPE_SDMMC_CMD, nomadDetachBus);
  perimanSetBusDeinit(ESP32_BUS_TYPE_SDMMC_D0, nomadDetachBus);
  perimanClearPinBus(s_pin_clk);
  perimanClearPinBus(s_pin_cmd);
  perimanClearPinBus(s_pin_d0);
  if (!mode1bit) {
    perimanSetBusDeinit(ESP32_BUS_TYPE_SDMMC_D1, nomadDetachBus);
    perimanSetBusDeinit(ESP32_BUS_TYPE_SDMMC_D2, nomadDetachBus);
    perimanSetBusDeinit(ESP32_BUS_TYPE_SDMMC_D3, nomadDetachBus);
    perimanClearPinBus(s_pin_d1);
    perimanClearPinBus(s_pin_d2);
    perimanClearPinBus(s_pin_d3);
  }

  sdmmc_slot_config_t slot_config = SDMMC_SLOT_CONFIG_DEFAULT();
  slot_config.clk = (gpio_num_t)s_pin_clk;
  slot_config.cmd = (gpio_num_t)s_pin_cmd;
  slot_config.d0 = (gpio_num_t)s_pin_d0;
  slot_config.d1 = (gpio_num_t)s_pin_d1;
  slot_config.d2 = (gpio_num_t)s_pin_d2;
  slot_config.d3 = (gpio_num_t)s_pin_d3;
  slot_config.width = mode1bit ? 1 : 4;

  sdmmc_host_t host = SDMMC_HOST_DEFAULT();
  host.slot = SDMMC_HOST_SLOT_1;
  host.flags = mode1bit ? SDMMC_HOST_FLAG_1BIT : SDMMC_HOST_FLAG_4BIT;
  host.max_freq_khz = freq_khz;

  esp_err_t err = sdmmc_host_init();
  bool hostFresh = (err == ESP_OK);
  if (err != ESP_OK && err != ESP_ERR_INVALID_STATE) {
    log_e("NomadSD: sdmmc_host_init failed (0x%x)", err);
    return false;
  }
  err = sdmmc_host_init_slot(SDMMC_HOST_SLOT_1, &slot_config);
  if (err != ESP_OK) {
    log_e("NomadSD: sdmmc_host_init_slot failed (0x%x)", err);
    if (hostFresh) sdmmc_host_deinit();
    return false;
  }
  memset(&s_card, 0, sizeof(s_card));
  err = sdmmc_card_init(&host, &s_card);
  if (err != ESP_OK) {
    log_e("NomadSD: sdmmc_card_init failed (0x%x) - check card and pull-ups", err);
    sdmmc_host_deinit();
    return false;
  }

  s_mode1bit = mode1bit;
  s_cardInited = true;

  // pin bookkeeping mirrors SD_MMC; failure here is non-fatal for us
  perimanSetPinBus(s_pin_cmd, ESP32_BUS_TYPE_SDMMC_CMD, (void *)&NomadSD, -1, -1);
  perimanSetPinBus(s_pin_clk, ESP32_BUS_TYPE_SDMMC_CLK, (void *)&NomadSD, -1, -1);
  perimanSetPinBus(s_pin_d0, ESP32_BUS_TYPE_SDMMC_D0, (void *)&NomadSD, -1, -1);
  if (!mode1bit) {
    perimanSetPinBus(s_pin_d1, ESP32_BUS_TYPE_SDMMC_D1, (void *)&NomadSD, -1, -1);
    perimanSetPinBus(s_pin_d2, ESP32_BUS_TYPE_SDMMC_D2, (void *)&NomadSD, -1, -1);
    perimanSetPinBus(s_pin_d3, ESP32_BUS_TYPE_SDMMC_D3, (void *)&NomadSD, -1, -1);
  }
  return true;
}

// ---------------------------------------------------------------- helpers

static String normalizePath(const char *path) {
  if (!path || !*path) return String("/");
  String p(path);
  if (p[0] != '/') p = "/" + p;
  while (p.length() > 1 && p.endsWith("/")) p.remove(p.length() - 1);
  return p;
}

// FS.h open modes ("r","w","a","r+","w+","a+") -> SdFat oflags
static oflag_t modeToOflag(const char *mode) {
  bool r = false, w = false, a = false, plus = false;
  for (const char *p = mode ? mode : "r"; *p; ++p) {
    if (*p == 'r') r = true;
    else if (*p == 'w') w = true;
    else if (*p == 'a') a = true;
    else if (*p == '+') plus = true;
  }
  (void)r;
  if (a) return plus ? (O_RDWR | O_CREAT | O_APPEND) : (O_WRONLY | O_CREAT | O_APPEND);
  if (w) return plus ? (O_RDWR | O_CREAT | O_TRUNC) : (O_WRONLY | O_CREAT | O_TRUNC);
  return plus ? O_RDWR : O_RDONLY;
}
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

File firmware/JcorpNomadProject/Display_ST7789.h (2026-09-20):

#pragma once
#include <Arduino.h>
#include <SPI.h>
#define LCD_WIDTH   172 //LCD width
#define LCD_HEIGHT  320 //LCD height

#define SPIFreq                        80000000
#define EXAMPLE_PIN_NUM_MISO           -1
#define EXAMPLE_PIN_NUM_MOSI           45
#define EXAMPLE_PIN_NUM_SCLK           40
#define EXAMPLE_PIN_NUM_LCD_CS         42
#define EXAMPLE_PIN_NUM_LCD_DC         41
#define EXAMPLE_PIN_NUM_LCD_RST        39
// backlight pin, and the only firmware-visible difference between the two boards:
// the 1.47 (USB-A) drives it from GPIO 48, the 1.47B (USB-C) from GPIO 46.
//   BOARD_USB_C 0 -> GPIO 48, USB-A (default)
//   BOARD_USB_C 1 -> GPIO 46, USB-C / 1.47B
// edit the 0 below, or build with -DBOARD_USB_C=1.
//
// it has to be set HERE, not in the .ino. the pin is used in Display_ST7789.cpp, which
// is its own translation unit, so a define in the sketch never reaches it and the board
// keeps GPIO 48 with no error and a dark screen. every file that needs the pin includes
// this header, which is why setting it here works.
#ifndef BOARD_USB_C
#define BOARD_USB_C 0
#endif

#if BOARD_USB_C
#define EXAMPLE_PIN_NUM_BK_LIGHT       46
#else
#define EXAMPLE_PIN_NUM_BK_LIGHT       48
#endif
#define Frequency       1000                    // PWM frequencyconst 
#define Resolution      10                      

#define VERTICAL   0
#define HORIZONTAL 1

#define Offset_X 34
#define Offset_Y 0


void LCD_SetCursor(uint16_t x1, uint16_t y1, uint16_t x2,uint16_t y2);

void LCD_Init(void);
void LCD_SetRotation180(bool flip);
void LCD_SetCursor(uint16_t Xstart, uint16_t Ystart, uint16_t Xend, uint16_t  Yend);
void LCD_addWindow(uint16_t Xstart, uint16_t Ystart, uint16_t Xend, uint16_t Yend,uint16_t* color);

void Backlight_Init(void);
void Set_Backlight(uint8_t Light);

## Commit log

2026-07-20 Experimental: exFAT firmware 4.6, offline maps, built-in games, local multiplayer
    Adds SdFat-based exFAT/FAT32/FAT16 support (NomadSD), offline raster maps
    with a Washington DC demo region, built-in HTML games with cover art,
    local multiplayer, and a pre-indexed demo Wikipedia archive.
    Demo media re-encoded to keep the template small.
    [BOM.csv, words-0.skp, words-1.skp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]
2026-07-27 WiFi Mode: join an existing network with hotspot fallback, DLNA discovery fix + posters, admin rework, new games, stability sweep
    [BOM.csv, Calibration Cube 20mm.stl, Hex Coaster 80mm.stl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]
2026-08-18 Add USB-C case STL and backlight port option to support board ESP32-S3-LCD-1.47B (#137)
    * Add USB-C case STL and backlight port option to support board ESP32-S3-LCD-1.47B
    * Update readme to say USB-A instead of micro
    * Update usb-c case
    ---------
    [NomadCasev30_USB-C.stl]
2026-09-20 Update hardware requirements with additional Amazon link
    Added Amazon link for ESP32-S3-LCD-1.47B board.
2026-10-15 Change audio encoder fallback to 'av_aac' (#146)
    Updated audio encoder settings in the HandBrake JSON configuration.
